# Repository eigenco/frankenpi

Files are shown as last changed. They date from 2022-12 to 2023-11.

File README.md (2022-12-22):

# frankenpi

This is an experimental project to connect Raspberry Pi with the help of cheap Cyclone IV FPGA board to 8-bit ISA bus to act as multiple different devices.

What is currently implemented (to some degree), i.e. PC can access through ISA
- Mass storage access from a file on the Raspberry Pi (written sectors are flushed every 2 seconds by default)
- Adlib output to optical SPDIF
- Sound Blaster 8-bit mono with DMA and IRQ (basic functions only), output to optical SPDIF
- Gravis Ultrasound (basic wavetable only), output to optical SPDIF
- Roland MT-32 (UART only), output to optical SPDIF
- USB mouse plugged into the Raspberry Pi will appear as a kind of serial mouse in DOS, custom ctmouse driver is provided (start with /v)
- Boot from custom TVGA9000i VGABIOS, i.e. no other devices are required to be present in the ISA bus besides FrakenPi and VGA-adapter

Youtube links:

https://www.youtube.com/watch?v=1ej76w8sHxY

https://www.youtube.com/watch?v=CkwgHHmKaSI

TESTED and working:
- Wolfenstein 3D (SB & Adlib)
- Second Reality (GUS)
- Scream Tracker 3.21 (SB1 and GUS)
- Skyroads (SB & Adlib)
- Keen 4 (Adlib)
- Monkey Island (Adlib/MT32/Mouse)
- Space Quest 3 (Adlib/Mouse)
- Space Quest 4 (Adlib/MT32/Mouse)
- Lotus 3 (Adlib)
- Lemmings (Adlib/Mouse)
- Eye of the Beholder I & II (Adlib/Mouse)
- Indiana Jones and the Fate of Atlantis (Adlib/MT32/Mouse)

Planned
- General MIDI
- MPU-401 support
- Sound Blaster AWE32 wavetable support
- Standard ATA at ports 1f0h-1f7h
- Compatibility improvements
- Boot ROM in the FPGA so hacked VGABIOS isn't required
- VGA output

Used resources
- Harddisk: ports 170h-171h
- SoundBlaster: ports 22ah-22eh corresponding ot base address of 220h, IRQ 7 and DMA 1
- MT32: 330h-331h
- Gravis Ultrasound: ports 341h-347h corresponding to base address of 240h
- Adlib: ports 388h-389h (standard)
- Mouse: port 3f8h and IRQ 4 (COM1)
- Bootcode for custom int 13h resides in hacked VGABIOS at the end of C0000-C7FFF memory region

Further explanation
- Outgoing port operations are transferred from the FPGA to the Raspberry Pi GPIO using dedicated unidirectional 8-bit data bus
- Incoming data from the Raspberry Pi GPIO (PCM, harddisk, mouse) is transferred using dedicated unidirectional 8-bit data bus
- Raspberry Pi: CPU0 handles hdd flushing and mouse, CPU1 handles GPIO transfers, CPU2 handles Adlib, Gravis Ultrasound and MT32 (software selected)
- Raspberry Pi operates with CPU1-CPU3 in isolated mode, all CPUs run at constant 1 GHz and sched_rt_runtime_us is -1
- Raspberry Pi generates sound data 64 samples at a time (16-bit stereo corresponds to 256 bytes it must transfer every 1.45ms or so)
- SPDIF is running in 24-bit 44100 Hz Stereo
- Hardcoded harddisk type is CHS 256/16/63, i.e. approx. 126MiB

Plan for the next PCB
- ICE40HX8K-CT256 (FPGA) seems to be available at Mouser
- IS61WV102416FBLL-10TLI (2 MByte SRAM) seem to be available at Mouser
- Created KiCAD project (PCB_v2)

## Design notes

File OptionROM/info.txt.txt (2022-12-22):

cf000h in binary is 1100 1111 0000 0000 0000

R0 1
R1 1
R2 1
R3 1
R4 0 (needs ground jumper)
R5 0 (needs ground jumpter)
R6 1
R7 1

[---]
[   ]
[---]
[   ]
[   ]
[   ]
[   ]
[   ]

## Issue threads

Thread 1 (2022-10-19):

FPGA Board

jshield, 2022-10-19:
Hello, I saw you mentioned using a cheap Altera Cyclone IV Board,

does it have a make/model, where did you source it from?

Cheers,

eigenco, 2022-10-19:
It was/is one of the brandless what used to be cheap Chinese Cyclone IV boards from ebay. Unfortunately getting FPGAs is next to impossible at the moment due to chip shortage. Someone might occasionally still sell them, but the prices are usually excessive. I paid for my board something like 10 eur before covid, but now I've seen sellers asking over 200 eur for similar very simple boards. When chips become available again, I might design my own PCB for whatever is properly available and makes sense then, perhaps even a complete self contained FPGA board so a separate module would not be needed, but for the moment it seems one has to wait.

AK6DN, 2022-11-13:
Are you running the Cyclone IV FPGA device out of spec? The Cyclone IV device has an absolute maximum limit of 4.2V on it's I/Os.
They are 3.3V I/O level compatible at most, they are NOT 5.0V I/O compatible.
The PC bus uses 5.0V I/O levels.
Normally one would use 5V/3.3V I/O translators on those signals (ie, like a TXB0104 device).

eigenco, 2022-11-14:
Yes, the input voltage is out of spec. Never the less, it doesn't seem to be problem so far. I've run the board for 100s of hours without an issue so I will probably only make changes if I design a new board for broad audience, but so far when FPGAs are not available I didn't bother with it as software development didn't suffer.

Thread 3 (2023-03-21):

Mass-stogate: Mounting of remote filesystems (instead of block images) on raspberry pi is possible.

peterzieba, 2023-03-21:
Hi,

I wanted to mention that for the mass-storage functionality, I think it should be possible to mount an entire filesystem on the raspberry pi without having to treat it as block device image and periodic sync/flush.

This can be achieved using Int 2Fh, which was originally intended to allow dos to mount network filesystems, but is also used by MSCDEX and such. This apparently works in any MS-DOS version since 3.3, and is used by projects like Netpi-IDE

https://web.archive.org/web/20221201103702/https://www.retrotronics.org/home-page/netpi-ide/

Essentially, a small TSR on the DOS side would use Int 2F to export a whole filesystem off of the Pi, at which point the possibilities on the Pi side are almost endless for different filesystem and network shares. Communication between the Pi and the host machine would simply be over an IO port, and a daemon on the Pi end listening to that address would receive requests from the TSR and serve files/directory information accordingly.

This eliminates sync problems, mounting, etc.

Anyway, I love seeing ISA bus projects!

Cheers

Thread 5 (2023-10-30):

Reverse FrankenPi (PiFranken?)

jamesfmackenzie, 2023-10-30:
The idea of connecting the Pi to an ISA backplane really appeals to me. So the Pi emulates an 8088 CPU, and can interface with peripherals like sound cards, network cards, video cards etc on an ISA bus.

Could the FrankenPi be used in "reverse" like this?

eigenco, 2023-11-06:
I did something like this corresponding to my RPiISA repository here now:

https://www.youtube.com/watch?v=V3mTAtPauRs

jamesfmackenzie, 2023-11-07:
This is fantastic! Would love to try this out too, but unfortunately I'm a software developer with no soldering skills :-)

Thanks for the KiCAD files! Can I get a company like JLCPCB to assemble, or is hand soldering still required for some components?

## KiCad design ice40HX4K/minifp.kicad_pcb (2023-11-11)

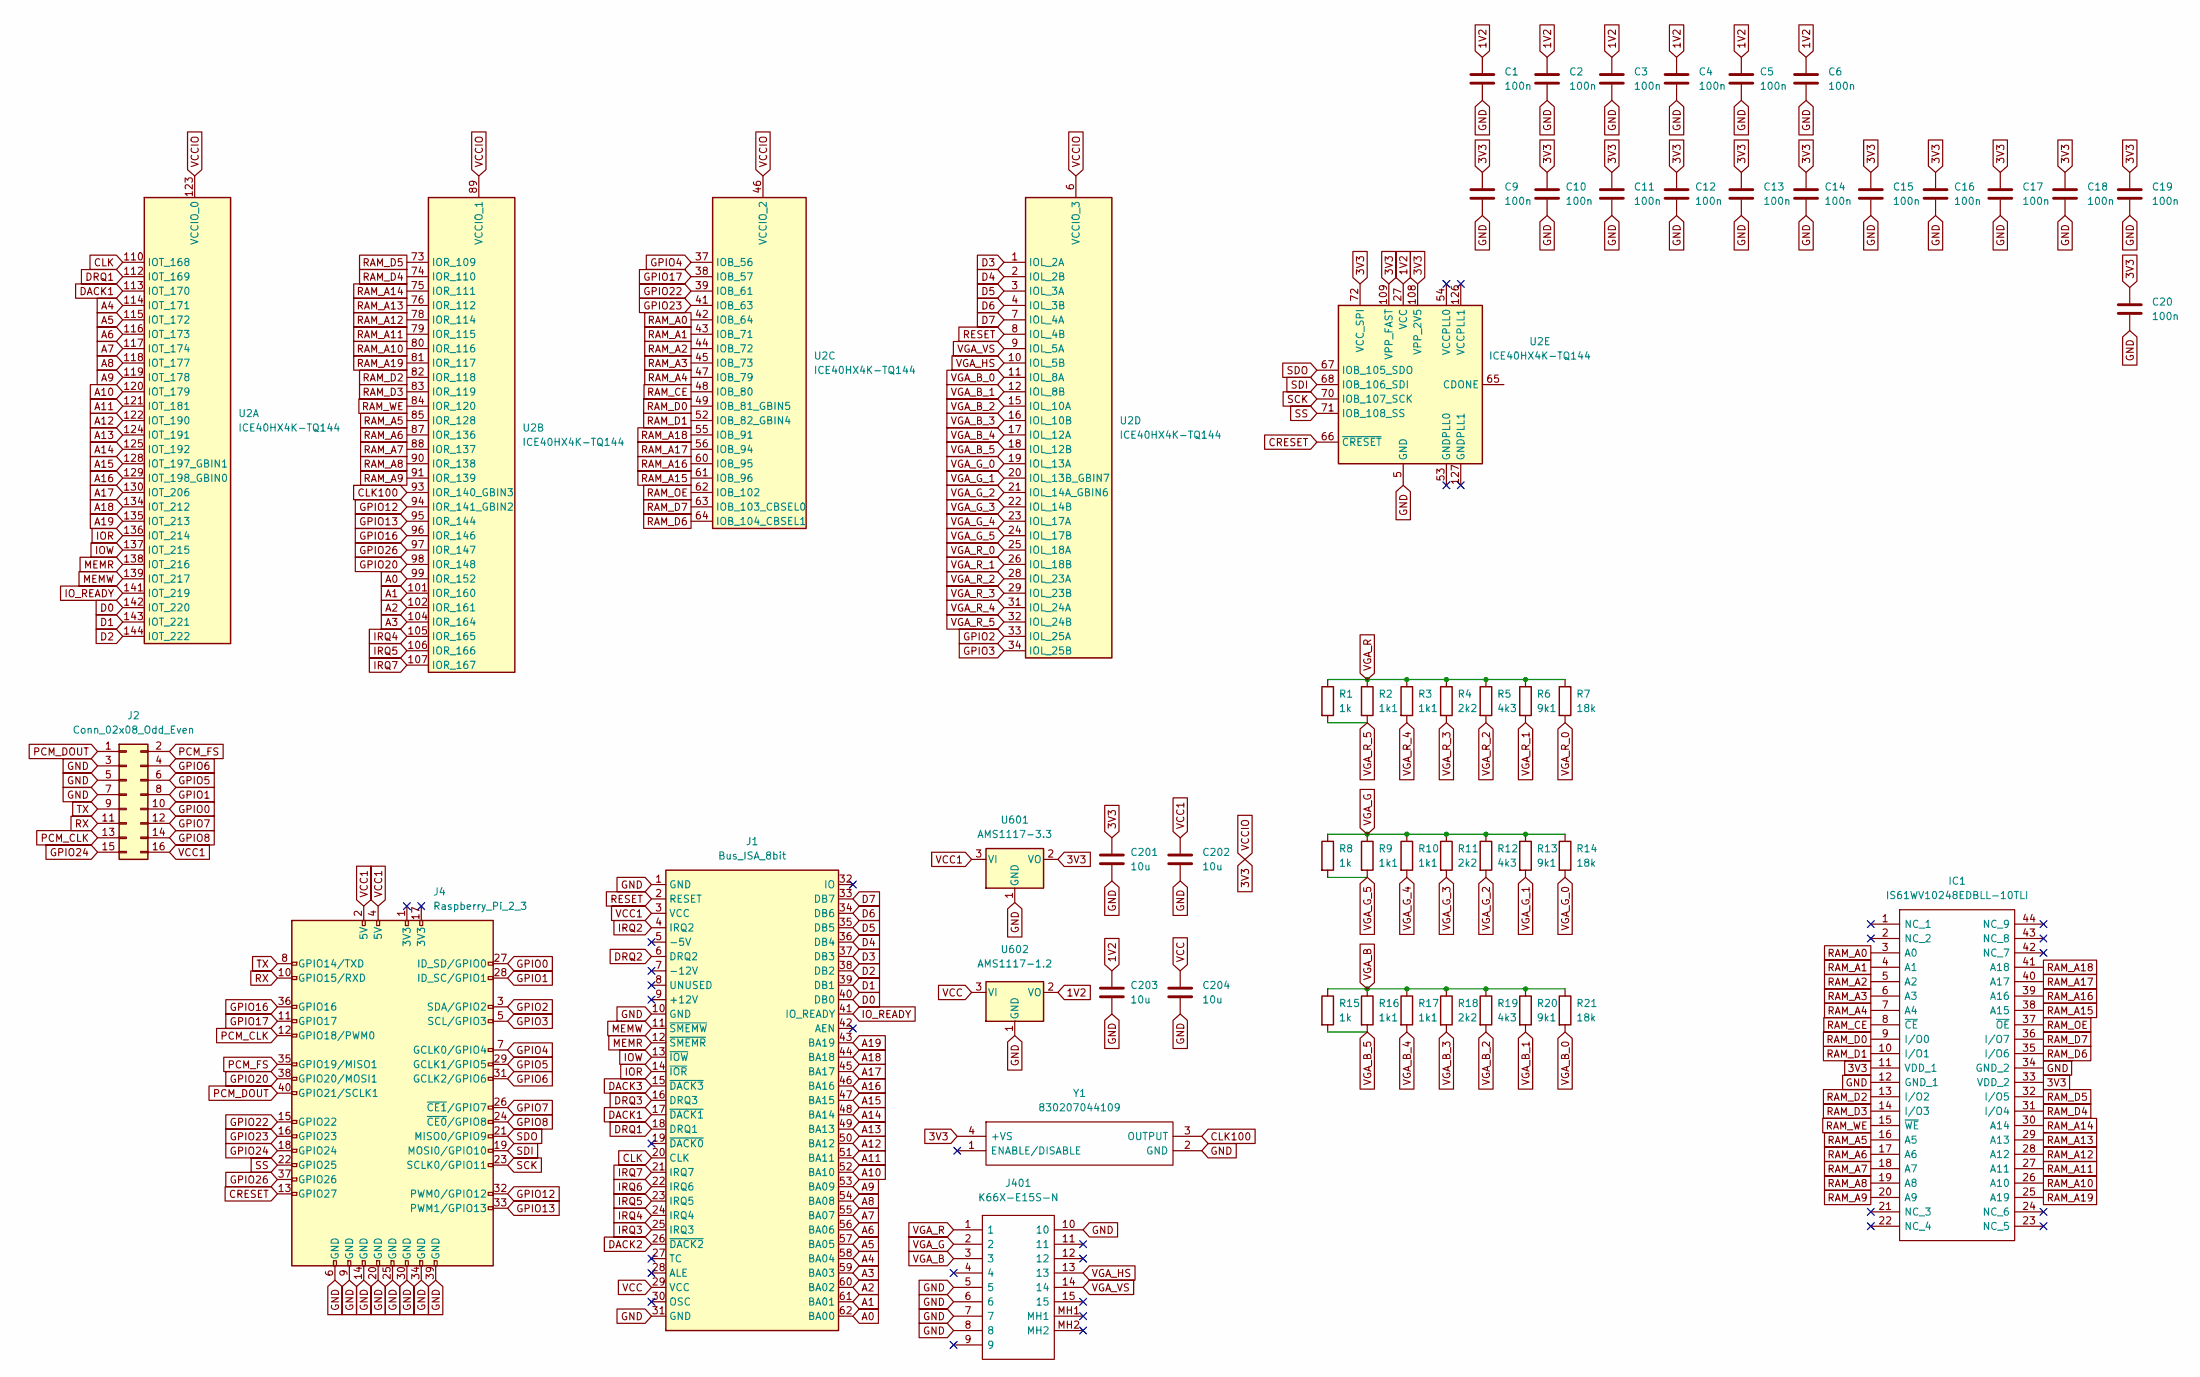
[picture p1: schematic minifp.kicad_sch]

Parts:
C1, C2, C3, C4, C5, C6, C9, C10, C11, C12, C13, C14, C15, C16, C17, C18, C19, C20: 100n; C_0603_1608Metric
C201, C202, C203, C204: 10u; C_0603_1608Metric
IC1: IS61WV10248EDBLL-10TLI; SOP80P1176X120-44N; Mouser Part Number 870-61WV10EDBLL10TLI
J1: Bus_ISA_8bit; Conn_Bus_ISA8
J2: Conn_02x08_Odd_Even; PinHeader_2x08_P1.27mm_Vertical
J4: Raspberry_Pi_2_3; PinHeader_2x20_P2.54mm_Vertical
J401: K66X-E15S-N; K66XE15SN; Mouser Part Number 806-K66X-E15S-N
R1, R8, R15: 1k; R_0603_1608Metric
R2, R3, R9, R10, R16, R17: 1k1; R_0603_1608Metric
R4, R11, R18: 2k2; R_0603_1608Metric
R5, R12, R19: 4k3; R_0603_1608Metric
R6, R13, R20: 9k1; R_0603_1608Metric
R7, R14, R21: 18k; R_0603_1608Metric
U2: ICE40HX4K-TQ144; TQFP-144_20x20mm_P0.5mm
U601: AMS1117-3.3; SOT-223-3_TabPin2
U602: AMS1117-1.2; SOT-223-3_TabPin2
Y1: 830207044109; Manufacturer_Part_Number 830207044109

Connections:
1V2: C1.1, C2.1, C3.1, C4.1, C5.1, C6.1, C203.1, U2.27 (VCC), U2.40 (VCC), U2.92 (VCC), U2.111 (VCC), U602.2 (VO)
3V3: C9.1, C10.1, C11.1, C12.1, C13.1, C14.1, C15.1, C16.1, C17.1, C18.1, C19.1, C20.1, C201.1, IC1.11 (VDD_1), IC1.33 (VDD_2), U2.6 (VCCIO_3), U2.30 (VCCIO_3), U2.46 (VCCIO_2), U2.57 (VCCIO_2), U2.72 (VCC_SPI), U2.89 (VCCIO_1), U2.100 (VCCIO_1), U2.108 (VPP_2V5), U2.109 (VPP_FAST), U2.123 (VCCIO_0), U2.131 (VCCIO_0), U601.2 (VO), Y1.4 (+VS)
A0: J1.62 (BA00), U2.99 (IOR_152)
A1: J1.61 (BA01), U2.101 (IOR_160)
A2: J1.60 (BA02), U2.102 (IOR_161)
A3: J1.59 (BA03), U2.104 (IOR_164)
A4: J1.58 (BA04), U2.114 (IOT_171)
A5: J1.57 (BA05), U2.115 (IOT_172)
A6: J1.56 (BA06), U2.116 (IOT_173)
A7: J1.55 (BA07), U2.117 (IOT_174)
A8: J1.54 (BA08), U2.118 (IOT_177)
A9: J1.53 (BA09), U2.119 (IOT_178)
A10: J1.52 (BA10), U2.120 (IOT_179)
A11: J1.51 (BA11), U2.121 (IOT_181)
A12: J1.50 (BA12), U2.122 (IOT_190)
A13: J1.49 (BA13), U2.124 (IOT_191)
A14: J1.48 (BA14), U2.125 (IOT_192)
A15: J1.47 (BA15), U2.128 (IOT_197_GBIN1)
A16: J1.46 (BA16), U2.129 (IOT_198_GBIN0)
A17: J1.45 (BA17), U2.130 (IOT_206)
A18: J1.44 (BA18), U2.134 (IOT_212)
A19: J1.43 (BA19), U2.135 (IOT_213)
CLK: J1.20 (CLK), U2.110 (IOT_168)
CLK100: U2.93 (IOR_140_GBIN3), Y1.3 (OUTPUT)
CRESET: J4.13 (GPIO27), U2.66 (~CRESET)
D0: J1.40 (DB0), U2.142 (IOT_220)
D1: J1.39 (DB1), U2.143 (IOT_221)
D2: J1.38 (DB2), U2.144 (IOT_222)
D3: J1.37 (DB3), U2.1 (IOL_2A)
D4: J1.36 (DB4), U2.2 (IOL_2B)
D5: J1.35 (DB5), U2.3 (IOL_3A)
D6: J1.34 (DB6), U2.4 (IOL_3B)
D7: J1.33 (DB7), U2.7 (IOL_4A)
DACK1: J1.17 (~DACK1), U2.113 (IOT_170)
DACK2: J1.26 (~DACK2)
DACK3: J1.15 (~DACK3)
DRQ1: J1.18 (DRQ1), U2.112 (IOT_169)
DRQ2: J1.6 (DRQ2)
DRQ3: J1.16 (DRQ3)
GND: C1.2, C2.2, C3.2, C4.2, C5.2, C6.2, C9.2, C10.2, C11.2, C12.2, C13.2, C14.2, C15.2, C16.2, C17.2, C18.2, C19.2, C20.2, C201.2, C202.2, C203.2, C204.2, IC1.12 (GND_1), IC1.34 (GND_2), J1.1 (GND), J1.10 (GND), J1.31 (GND), J2.3, J2.5, J2.7, J4.6 (GND), J4.9 (GND), J4.14 (GND), J4.20 (GND), J4.25 (GND), J4.30 (GND), J4.34 (GND), J4.39 (GND), J401.5, J401.6, J401.7, J401.8, J401.10, U2.5 (GND), U2.13 (GND), U2.14 (GND), U2.59 (GND), U2.69 (GND), U2.86 (GND), U2.103 (GND), U2.132 (GND), U2.140 (GND), U601.1 (GND), U602.1 (GND), Y1.2 (GND)
GPIO0: J2.10, J4.27 (ID_SD/GPIO0)
GPIO1: J2.8, J4.28 (ID_SC/GPIO1)
GPIO2: J4.3 (SDA/GPIO2), U2.33 (IOL_25A)
GPIO3: J4.5 (SCL/GPIO3), U2.34 (IOL_25B)
GPIO4: J4.7 (GCLK0/GPIO4), U2.37 (IOB_56)
GPIO5: J2.6, J4.29 (GCLK1/GPIO5)
GPIO6: J2.4, J4.31 (GCLK2/GPIO6)
GPIO7: J2.12, J4.26 (~CE1/GPIO7)
GPIO8: J2.14, J4.24 (~CE0/GPIO8)
GPIO12: J4.32 (PWM0/GPIO12), U2.94 (IOR_141_GBIN2)
GPIO13: J4.33 (PWM1/GPIO13), U2.95 (IOR_144)
GPIO16: J4.36 (GPIO16), U2.96 (IOR_146)
GPIO17: J4.11 (GPIO17), U2.38 (IOB_57)
GPIO20: J4.38 (GPIO20/MOSI1), U2.98 (IOR_148)
GPIO22: J4.15 (GPIO22), U2.39 (IOB_61)
GPIO23: J4.16 (GPIO23), U2.41 (IOB_63)
GPIO24: J2.15, J4.18 (GPIO24)
GPIO26: J4.37 (GPIO26), U2.97 (IOR_147)
IOR: J1.14 (~IOR), U2.136 (IOT_214)
IOW: J1.13 (~IOW), U2.137 (IOT_215)
IO_READY: J1.41 (IO_READY), U2.141 (IOT_219)
IRQ2: J1.4 (IRQ2)
IRQ3: J1.25 (IRQ3)
IRQ4: J1.24 (IRQ4), U2.105 (IOR_165)
IRQ5: J1.23 (IRQ5), U2.106 (IOR_166)
IRQ6: J1.22 (IRQ6)
IRQ7: J1.21 (IRQ7), U2.107 (IOR_167)
MEMR: J1.12 (~SMEMR), U2.138 (IOT_216)
MEMW: J1.11 (~SMEMW), U2.139 (IOT_217)
PCM_CLK: J2.13, J4.12 (GPIO18/PWM0)
PCM_DOUT: J2.1, J4.40 (GPIO21/SCLK1)
PCM_FS: J2.2, J4.35 (GPIO19/MISO1)
RAM_A0: IC1.3 (A0), U2.42 (IOB_64)
RAM_A1: IC1.4 (A1), U2.43 (IOB_71)
RAM_A2: IC1.5 (A2), U2.44 (IOB_72)
RAM_A3: IC1.6 (A3), U2.45 (IOB_73)
RAM_A4: IC1.7 (A4), U2.47 (IOB_79)
RAM_A5: IC1.16 (A5), U2.85 (IOR_128)
RAM_A6: IC1.17 (A6), U2.87 (IOR_136)
RAM_A7: IC1.18 (A7), U2.88 (IOR_137)
RAM_A8: IC1.19 (A8), U2.90 (IOR_138)
RAM_A9: IC1.20 (A9), U2.91 (IOR_139)
RAM_A10: IC1.26 (A10), U2.80 (IOR_116)
RAM_A11: IC1.27 (A11), U2.79 (IOR_115)
RAM_A12: IC1.28 (A12), U2.78 (IOR_114)
RAM_A13: IC1.29 (A13), U2.76 (IOR_112)
RAM_A14: IC1.30 (A14), U2.75 (IOR_111)
RAM_A15: IC1.38 (A15), U2.61 (IOB_96)
RAM_A16: IC1.39 (A16), U2.60 (IOB_95)
RAM_A17: IC1.40 (A17), U2.56 (IOB_94)
RAM_A18: IC1.41 (A18), U2.55 (IOB_91)
RAM_A19: IC1.25 (A19), U2.81 (IOR_117)
RAM_CE: IC1.8 (~CE), U2.48 (IOB_80)
RAM_D0: IC1.9 (I/O0), U2.49 (IOB_81_GBIN5)
RAM_D1: IC1.10 (I/O1), U2.52 (IOB_82_GBIN4)
RAM_D2: IC1.13 (I/O2), U2.82 (IOR_118)
RAM_D3: IC1.14 (I/O3), U2.83 (IOR_119)
RAM_D4: IC1.31 (I/O4), U2.74 (IOR_110)
RAM_D5: IC1.32 (I/O5), U2.73 (IOR_109)
RAM_D6: IC1.35 (I/O6), U2.64 (IOB_104_CBSEL1)
RAM_D7: IC1.36 (I/O7), U2.63 (IOB_103_CBSEL0)
RAM_OE: IC1.37 (~OE), U2.62 (IOB_102)
RAM_WE: IC1.15 (~WE), U2.84 (IOR_120)
RESET: J1.2 (RESET), U2.8 (IOL_4B)
RX: J2.11, J4.10 (GPIO15/RXD)
SCK: J4.23 (SCLK0/GPIO11), U2.70 (IOB_107_SCK)
SDI: J4.19 (MOSI0/GPIO10), U2.68 (IOB_106_SDI)
SDO: J4.21 (MISO0/GPIO9), U2.67 (IOB_105_SDO)
SS: J4.22 (GPIO25), U2.71 (IOB_108_SS)
TX: J2.9, J4.8 (GPIO14/TXD)
VCC: C204.1, J1.29 (VCC), U602.3 (VI)
VCC1: C202.1, J1.3 (VCC), J2.16, J4.2 (5V), J4.4 (5V), U601.3 (VI)
VGA_B: J401.3, R15.1, R16.1, R17.1, R18.1, R19.1, R20.1, R21.1
VGA_B_0: R21.2, U2.11 (IOL_8A)
VGA_B_1: R20.2, U2.12 (IOL_8B)
VGA_B_2: R19.2, U2.15 (IOL_10A)
VGA_B_3: R18.2, U2.16 (IOL_10B)
VGA_B_4: R17.2, U2.17 (IOL_12A)
VGA_B_5: R15.2, R16.2, U2.18 (IOL_12B)
VGA_G: J401.2, R8.1, R9.1, R10.1, R11.1, R12.1, R13.1, R14.1
VGA_G_0: R14.2, U2.19 (IOL_13A)
VGA_G_1: R13.2, U2.20 (IOL_13B_GBIN7)
VGA_G_2: R12.2, U2.21 (IOL_14A_GBIN6)
VGA_G_3: R11.2, U2.22 (IOL_14B)
VGA_G_4: R10.2, U2.23 (IOL_17A)
VGA_G_5: R8.2, R9.2, U2.24 (IOL_17B)
VGA_HS: J401.13, U2.10 (IOL_5B)
VGA_R: J401.1, R1.1, R2.1, R3.1, R4.1, R5.1, R6.1, R7.1
VGA_R_0: R7.2, U2.25 (IOL_18A)
VGA_R_1: R6.2, U2.26 (IOL_18B)
VGA_R_2: R5.2, U2.28 (IOL_23A)
VGA_R_3: R4.2, U2.29 (IOL_23B)
VGA_R_4: R3.2, U2.31 (IOL_24A)
VGA_R_5: R1.2, R2.2, U2.32 (IOL_24B)
VGA_VS: J401.14, U2.9 (IOL_5A)

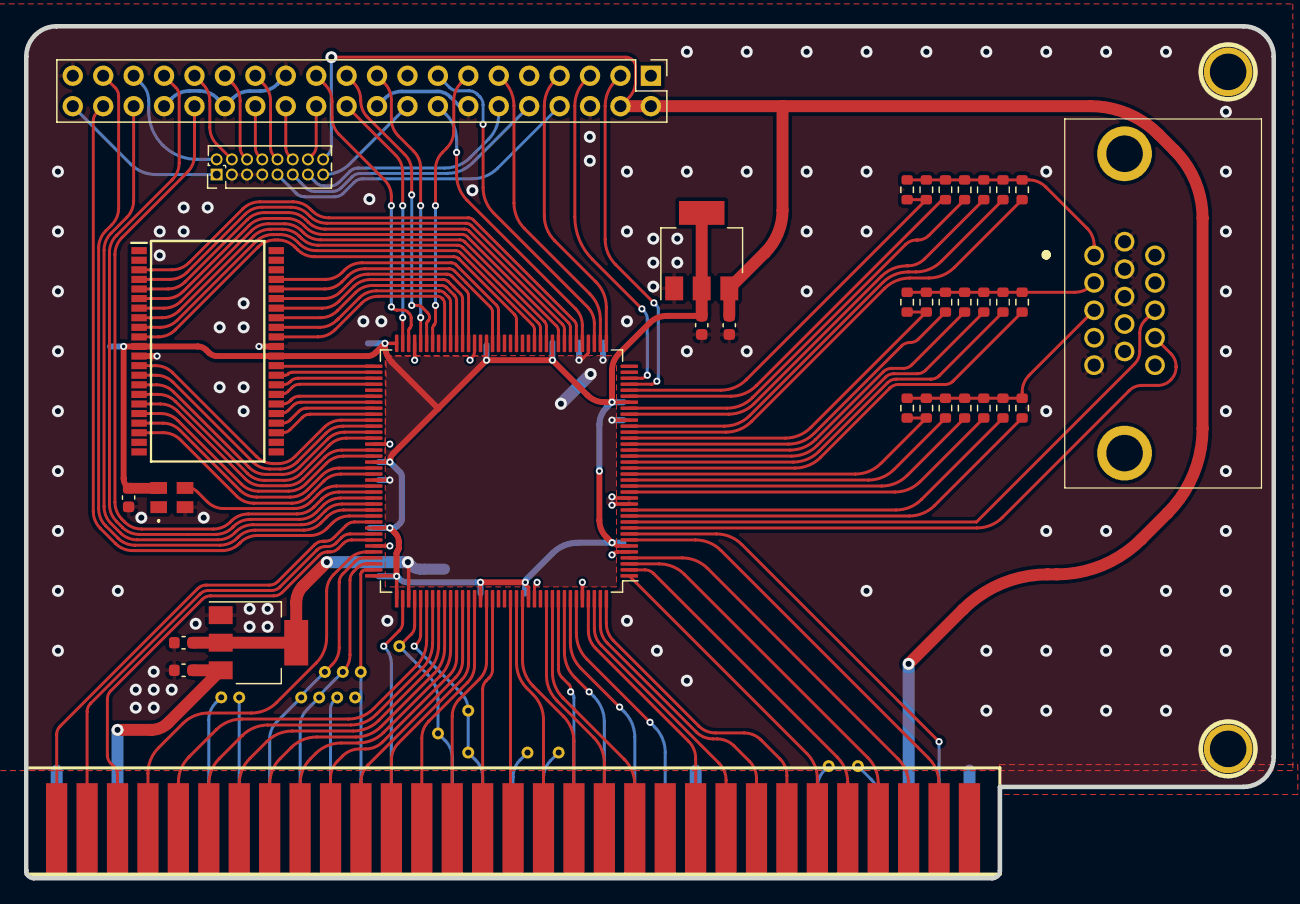
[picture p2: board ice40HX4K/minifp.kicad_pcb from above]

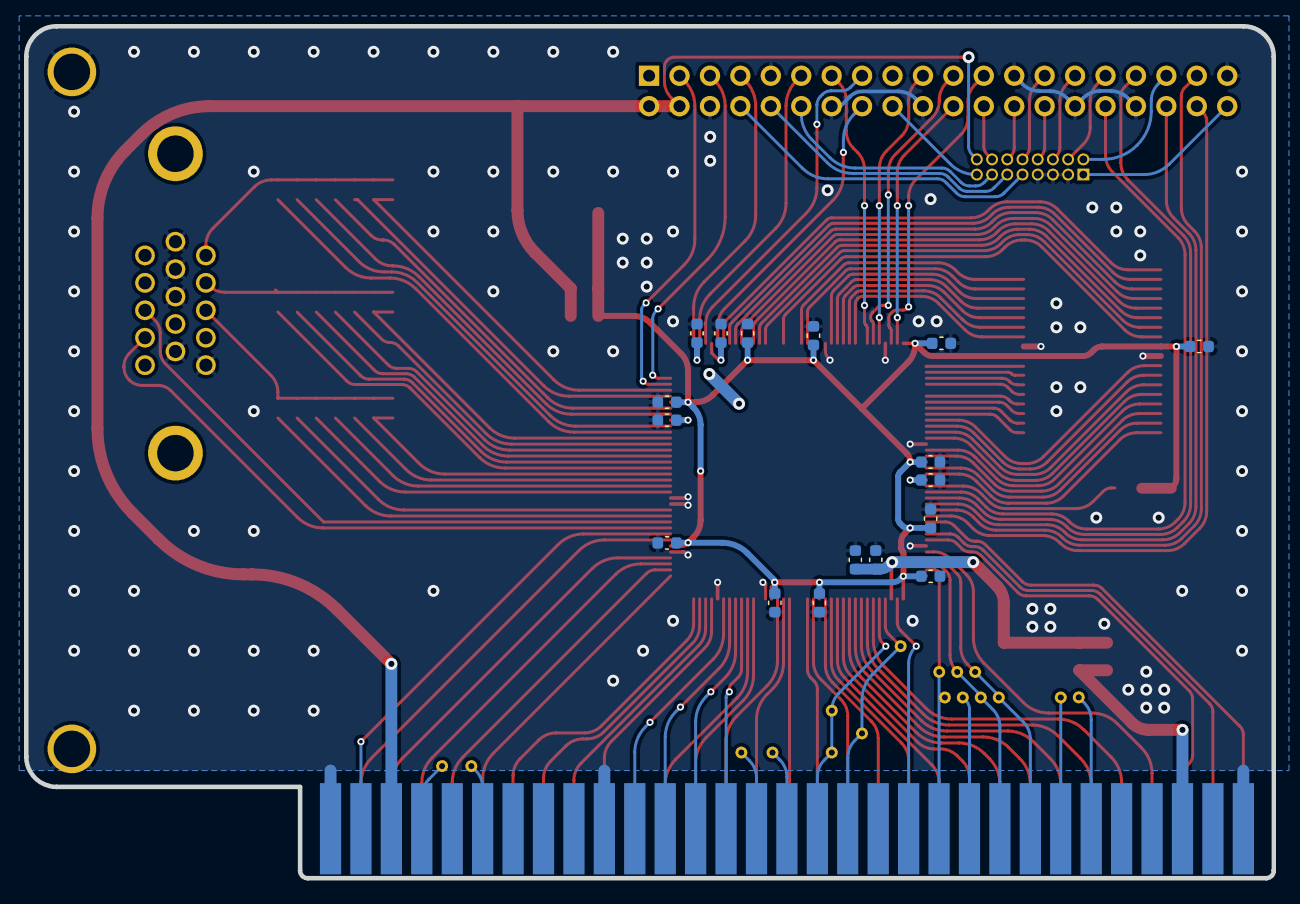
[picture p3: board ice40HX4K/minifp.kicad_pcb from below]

Board: 2 copper layers, 104.1 x 71.1 mm, 52 parts (17 on the bottom side), 128 nets.

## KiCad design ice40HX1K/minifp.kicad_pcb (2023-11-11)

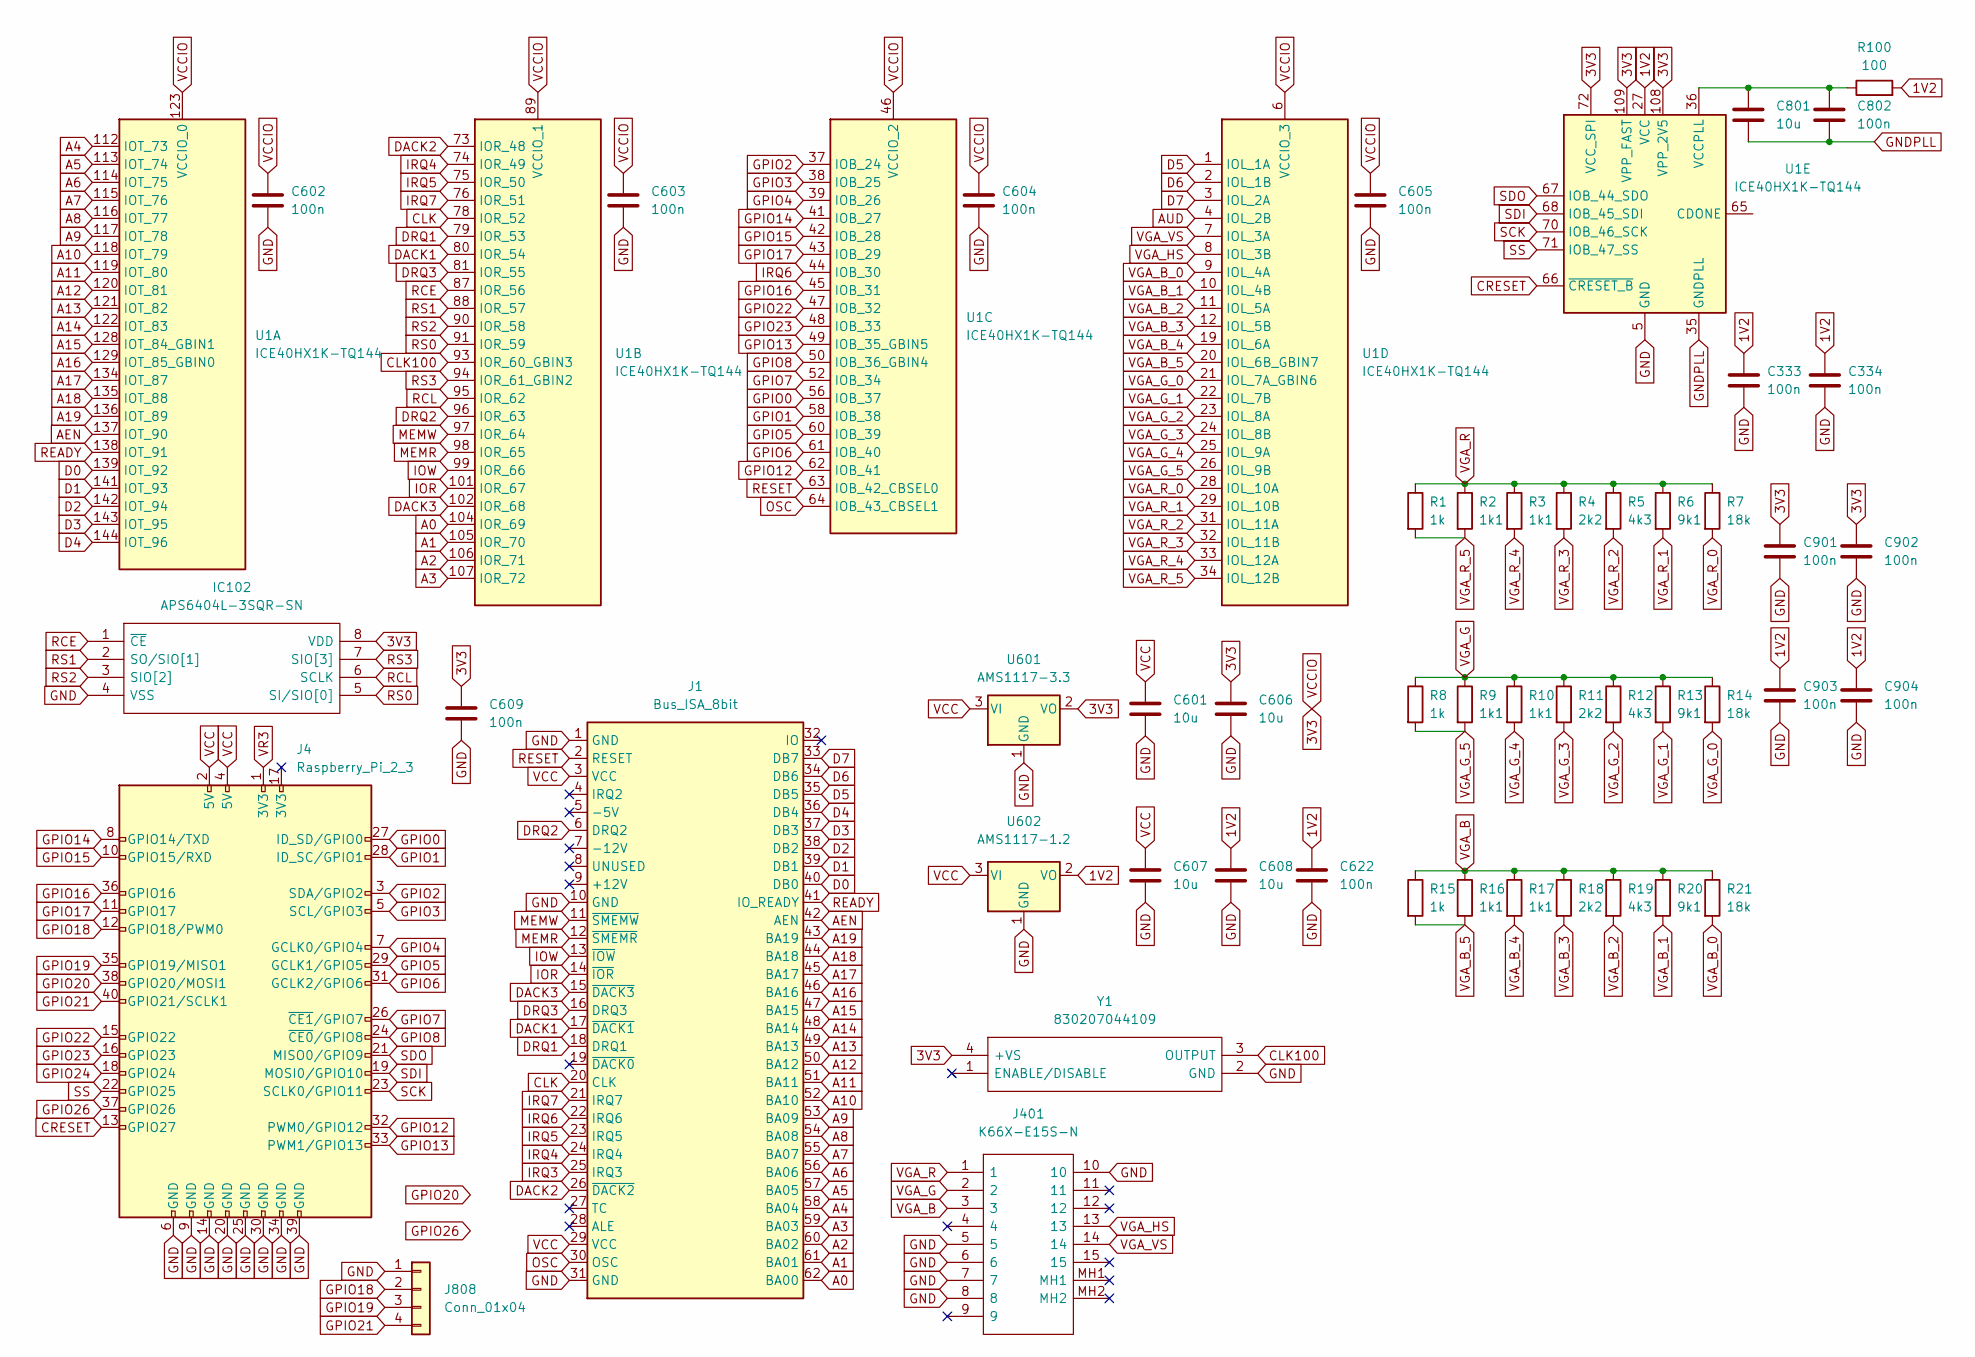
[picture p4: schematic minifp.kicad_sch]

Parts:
C333, C334, C602, C603, C604, C605, C609, C622, C802, C901, C902, C903, C904: 100n; C_0603_1608Metric
C601, C606, C607, C608, C801: 10u; C_0603_1608Metric
IC102: APS6404L-3SQR-SN; SOIC127P600X175-8N; Mouser Part Number 878-APS6404L-3SQR-SN
J1: Bus_ISA_8bit; Conn_Bus_ISA8
J4: Raspberry_Pi_2_3; PinHeader_2x20_P2.54mm_Vertical
J401: K66X-E15S-N; K66XE15SN; Mouser Part Number 806-K66X-E15S-N
J808: Conn_01x04; PinHeader_1x04_P2.54mm_Vertical
R1, R8, R15: 1k; R_0603_1608Metric
R2, R3, R9, R10, R16, R17: 1k1; R_0603_1608Metric
R4, R11, R18: 2k2; R_0603_1608Metric
R5, R12, R19: 4k3; R_0603_1608Metric
R6, R13, R20: 9k1; R_0603_1608Metric
R7, R14, R21: 18k; R_0603_1608Metric
R100: 100; R_0603_1608Metric
U1: ICE40HX1K-TQ144; TQFP-144_20x20mm_P0.5mm
U601: AMS1117-3.3; SOT-223-3_TabPin2
U602: AMS1117-1.2; SOT-223-3_TabPin2
Y1: 830207044109; Manufacturer_Part_Number 830207044109

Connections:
1V2: C333.1, C334.1, C608.1, C622.1, C903.1, C904.1, R100.2, U1.27 (VCC), U1.51 (VCC), U1.92 (VCC), U1.111 (VCC), U602.2 (VO)
3V3: C602.1, C603.1, C604.1, C605.1, C606.1, C609.1, C901.1, C902.1, IC102.8 (VDD), U1.6 (VCCIO_3), U1.30 (VCCIO_3), U1.46 (VCCIO_2), U1.57 (VCCIO_2), U1.72 (VCC_SPI), U1.89 (VCCIO_1), U1.100 (VCCIO_1), U1.108 (VPP_2V5), U1.109 (VPP_FAST), U1.123 (VCCIO_0), U1.133 (VCCIO_0), U601.2 (VO), Y1.4 (+VS)
A0: J1.62 (BA00), U1.104 (IOR_69)
A1: J1.61 (BA01), U1.105 (IOR_70)
A2: J1.60 (BA02), U1.106 (IOR_71)
A3: J1.59 (BA03), U1.107 (IOR_72)
A4: J1.58 (BA04), U1.112 (IOT_73)
A5: J1.57 (BA05), U1.113 (IOT_74)
A6: J1.56 (BA06), U1.114 (IOT_75)
A7: J1.55 (BA07), U1.115 (IOT_76)
A8: J1.54 (BA08), U1.116 (IOT_77)
A9: J1.53 (BA09), U1.117 (IOT_78)
A10: J1.52 (BA10), U1.118 (IOT_79)
A11: J1.51 (BA11), U1.119 (IOT_80)
A12: J1.50 (BA12), U1.120 (IOT_81)
A13: J1.49 (BA13), U1.121 (IOT_82)
A14: J1.48 (BA14), U1.122 (IOT_83)
A15: J1.47 (BA15), U1.128 (IOT_84_GBIN1)
A16: J1.46 (BA16), U1.129 (IOT_85_GBIN0)
A17: J1.45 (BA17), U1.134 (IOT_87)
A18: J1.44 (BA18), U1.135 (IOT_88)
A19: J1.43 (BA19), U1.136 (IOT_89)
AEN: J1.42 (AEN), U1.137 (IOT_90)
AUD: U1.4 (IOL_2B)
CLK: J1.20 (CLK), U1.78 (IOR_52)
CLK100: U1.93 (IOR_60_GBIN3), Y1.3 (OUTPUT)
CRESET: J4.13 (GPIO27), U1.66 (~CRESET_B)
D0: J1.40 (DB0), U1.139 (IOT_92)
D1: J1.39 (DB1), U1.141 (IOT_93)
D2: J1.38 (DB2), U1.142 (IOT_94)
D3: J1.37 (DB3), U1.143 (IOT_95)
D4: J1.36 (DB4), U1.144 (IOT_96)
D5: J1.35 (DB5), U1.1 (IOL_1A)
D6: J1.34 (DB6), U1.2 (IOL_1B)
D7: J1.33 (DB7), U1.3 (IOL_2A)
DACK1: J1.17 (~DACK1), U1.80 (IOR_54)
DACK2: J1.26 (~DACK2), U1.73 (IOR_48)
DACK3: J1.15 (~DACK3), U1.102 (IOR_68)
DRQ1: J1.18 (DRQ1), U1.79 (IOR_53)
DRQ2: J1.6 (DRQ2), U1.96 (IOR_63)
DRQ3: J1.16 (DRQ3), U1.81 (IOR_55)
GND: C333.2, C334.2, C601.2, C602.2, C603.2, C604.2, C605.2, C606.2, C607.2, C608.2, C609.2, C622.2, C901.2, C902.2, C903.2, C904.2, IC102.4 (VSS), J1.1 (GND), J1.10 (GND), J1.31 (GND), J4.6 (GND), J4.9 (GND), J4.14 (GND), J4.20 (GND), J4.25 (GND), J4.30 (GND), J4.34 (GND), J4.39 (GND), J401.5, J401.6, J401.7, J401.8, J401.10, J808.1, U1.5 (GND), U1.13 (GND), U1.14 (GND), U1.59 (GND), U1.69 (GND), U1.86 (GND), U1.103 (GND), U1.132 (GND), U1.140 (GND), U601.1 (GND), U602.1 (GND), Y1.2 (GND)
GNDPLL: C801.2, C802.2, U1.35 (GNDPLL)
GPIO0: J4.27 (ID_SD/GPIO0), U1.56 (IOB_37)
GPIO1: J4.28 (ID_SC/GPIO1), U1.58 (IOB_38)
GPIO2: J4.3 (SDA/GPIO2), U1.37 (IOB_24)
GPIO3: J4.5 (SCL/GPIO3), U1.38 (IOB_25)
GPIO4: J4.7 (GCLK0/GPIO4), U1.39 (IOB_26)
GPIO5: J4.29 (GCLK1/GPIO5), U1.60 (IOB_39)
GPIO6: J4.31 (GCLK2/GPIO6), U1.61 (IOB_40)
GPIO7: J4.26 (~CE1/GPIO7), U1.52 (IOB_34)
GPIO8: J4.24 (~CE0/GPIO8), U1.50 (IOB_36_GBIN4)
GPIO12: J4.32 (PWM0/GPIO12), U1.62 (IOB_41)
GPIO13: J4.33 (PWM1/GPIO13), U1.49 (IOB_35_GBIN5)
GPIO14: J4.8 (GPIO14/TXD), U1.41 (IOB_27)
GPIO15: J4.10 (GPIO15/RXD), U1.42 (IOB_28)
GPIO16: J4.36 (GPIO16), U1.45 (IOB_31)
GPIO17: J4.11 (GPIO17), U1.43 (IOB_29)
GPIO18: J4.12 (GPIO18/PWM0), J808.2
GPIO19: J4.35 (GPIO19/MISO1), J808.3
GPIO20: J4.38 (GPIO20/MOSI1)
GPIO21: J4.40 (GPIO21/SCLK1), J808.4
GPIO22: J4.15 (GPIO22), U1.47 (IOB_32)
GPIO23: J4.16 (GPIO23), U1.48 (IOB_33)
GPIO24: J4.18 (GPIO24)
GPIO26: J4.37 (GPIO26)
IOR: J1.14 (~IOR), U1.101 (IOR_67)
IOW: J1.13 (~IOW), U1.99 (IOR_66)
IRQ3: J1.25 (IRQ3)
IRQ4: J1.24 (IRQ4), U1.74 (IOR_49)
IRQ5: J1.23 (IRQ5), U1.75 (IOR_50)
IRQ6: J1.22 (IRQ6), U1.44 (IOB_30)
IRQ7: J1.21 (IRQ7), U1.76 (IOR_51)
MEMR: J1.12 (~SMEMR), U1.98 (IOR_65)
MEMW: J1.11 (~SMEMW), U1.97 (IOR_64)
unnamed: C801.1, C802.1, R100.1, U1.36 (VCCPLL)
OSC: J1.30 (OSC), U1.64 (IOB_43_CBSEL1)
RCE: IC102.1 (~CE), U1.87 (IOR_56)
RCL: IC102.6 (SCLK), U1.95 (IOR_62)
READY: J1.41 (IO_READY), U1.138 (IOT_91)
RESET: J1.2 (RESET), U1.63 (IOB_42_CBSEL0)
RS0: IC102.5 (SI/SIO[0]), U1.91 (IOR_59)
RS1: IC102.2 (SO/SIO[1]), U1.88 (IOR_57)
RS2: IC102.3 (SIO[2]), U1.90 (IOR_58)
RS3: IC102.7 (SIO[3]), U1.94 (IOR_61_GBIN2)
SCK: J4.23 (SCLK0/GPIO11), U1.70 (IOB_46_SCK)
SDI: J4.19 (MOSI0/GPIO10), U1.68 (IOB_45_SDI)
SDO: J4.21 (MISO0/GPIO9), U1.67 (IOB_44_SDO)
SS: J4.22 (GPIO25), U1.71 (IOB_47_SS)
VCC: C601.1, C607.1, J1.3 (VCC), J1.29 (VCC), J4.2 (5V), J4.4 (5V), U601.3 (VI), U602.3 (VI)
VGA_B: J401.3, R15.1, R16.1, R17.1, R18.1, R19.1, R20.1, R21.1
VGA_B_0: R21.2, U1.9 (IOL_4A)
VGA_B_1: R20.2, U1.10 (IOL_4B)
VGA_B_2: R19.2, U1.11 (IOL_5A)
VGA_B_3: R18.2, U1.12 (IOL_5B)
VGA_B_4: R17.2, U1.19 (IOL_6A)
VGA_B_5: R15.2, R16.2, U1.20 (IOL_6B_GBIN7)
VGA_G: J401.2, R8.1, R9.1, R10.1, R11.1, R12.1, R13.1, R14.1
VGA_G_0: R14.2, U1.21 (IOL_7A_GBIN6)
VGA_G_1: R13.2, U1.22 (IOL_7B)
VGA_G_2: R12.2, U1.23 (IOL_8A)
VGA_G_3: R11.2, U1.24 (IOL_8B)
VGA_G_4: R10.2, U1.25 (IOL_9A)
VGA_G_5: R8.2, R9.2, U1.26 (IOL_9B)
VGA_HS: J401.13, U1.8 (IOL_3B)
VGA_R: J401.1, R1.1, R2.1, R3.1, R4.1, R5.1, R6.1, R7.1
VGA_R_0: R7.2, U1.28 (IOL_10A)
VGA_R_1: R6.2, U1.29 (IOL_10B)
VGA_R_2: R5.2, U1.31 (IOL_11A)
VGA_R_3: R4.2, U1.32 (IOL_11B)
VGA_R_4: R3.2, U1.33 (IOL_12A)
VGA_R_5: R1.2, R2.2, U1.34 (IOL_12B)
VGA_VS: J401.14, U1.7 (IOL_3A)
VR3: J4.1 (3V3)

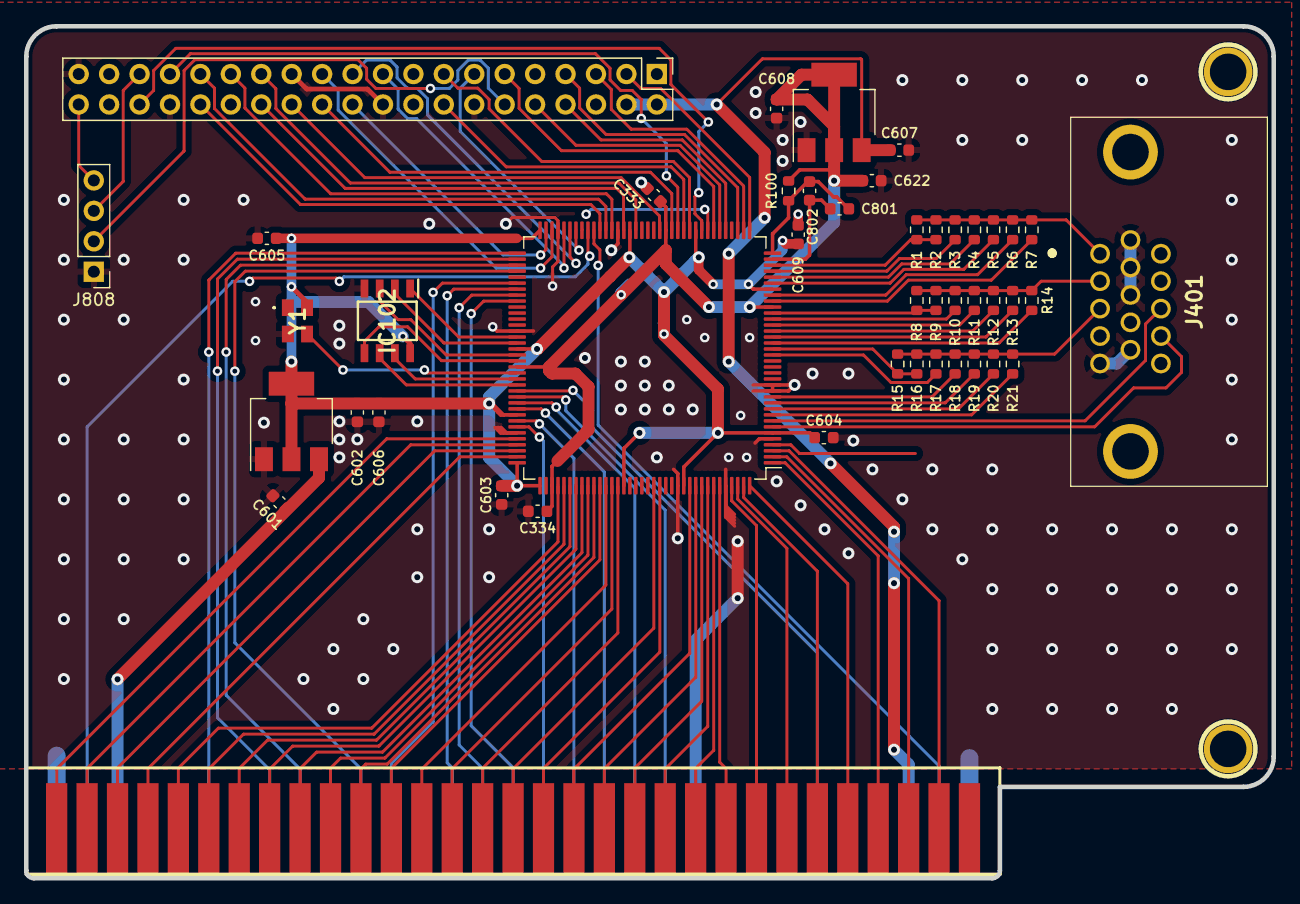
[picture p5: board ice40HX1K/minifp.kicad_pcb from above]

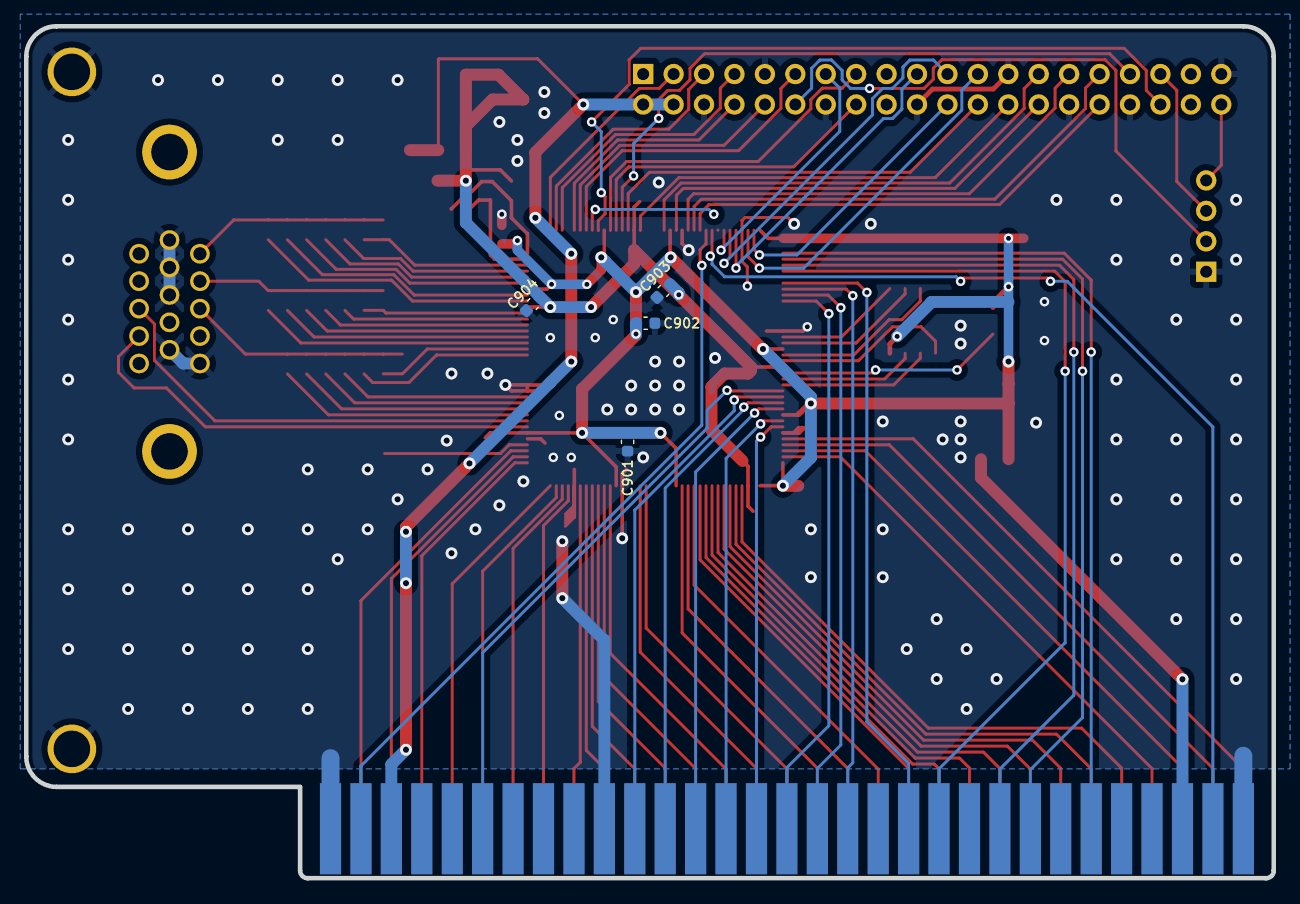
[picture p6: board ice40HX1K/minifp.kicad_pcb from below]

Board: 2 copper layers, 104.1 x 71.1 mm, 49 parts (4 on the bottom side), 108 nets.

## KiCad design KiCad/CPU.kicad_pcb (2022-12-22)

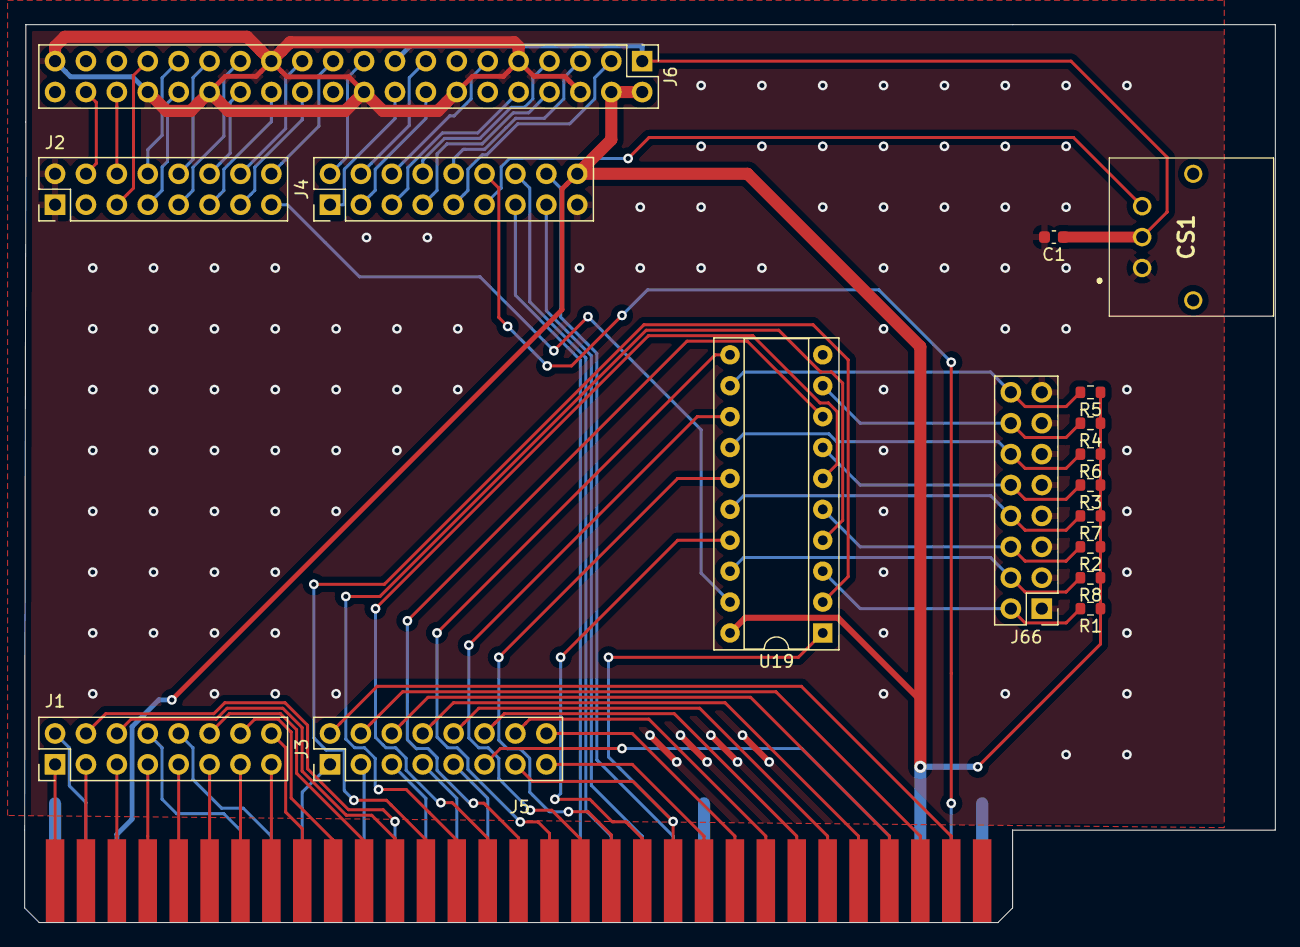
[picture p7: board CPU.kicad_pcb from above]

Board: 2 copper layers, 102.8 x 73.8 mm, 18 parts (0 on the bottom side), 80 nets.

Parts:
C1: 0.1u; C_0603_1608Metric
CS1: TOTX1350_F_; TOTX1350F
J1, J2, J3, J66: Conn_02x08_Odd_Even; PinHeader_2x08_P2.54mm_Vertical
J4: Conn_02x09_Odd_Even; PinHeader_2x09_P2.54mm_Vertical
J5: Bus_ISA_8bit; BUS_PC
J6: Raspberry_Pi_2_3; PinHeader_2x20_P2.54mm_Vertical
R1, R2, R3, R4, R5, R6, R7, R8: 10k; R_0603_1608Metric
U19: 74LS688; DIP-20_W7.62mm_Socket

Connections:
A0: J1.1, J5.62 (BA00)
A1: J1.3, J5.61 (BA01)
A2: J1.5, J5.60 (BA02)
A3: J1.7, J5.59 (BA03)
A4: J1.9, J5.58 (BA04)
A5: J1.11, J5.57 (BA05)
A6: J1.13, J5.56 (BA06)
A7: J1.15, J5.55 (BA07)
A8: J1.16, J5.54 (BA08)
A9: J1.14, J5.53 (BA09)
A10: J1.12, J5.52 (BA10)
A11: J1.6, J5.51 (BA11)
A12: J5.50 (BA12), U19.2 (P0)
A13: J5.49 (BA13), U19.4 (P1)
A14: J5.48 (BA14), U19.6 (P2)
A15: J5.47 (BA15), U19.8 (P3)
A16: J5.46 (BA16), U19.11 (P4)
A17: J5.45 (BA17), U19.13 (P5)
A18: J5.44 (BA18), U19.15 (P6)
A19: J5.43 (BA19), U19.17 (P7)
AEN: J3.13, J5.42 (AEN), U19.1 (G)
CLK: J1.4, J5.20 (CLK)
D0: J3.16, J5.40 (DB0)
D1: J3.14, J5.39 (DB1)
D2: J3.12, J5.38 (DB2)
D3: J3.10, J5.37 (DB3)
D4: J3.8, J5.36 (DB4)
D5: J3.6, J5.35 (DB5)
D6: J3.4, J5.34 (DB6)
D7: J3.2, J5.33 (DB7)
DRQ1: J3.7, J5.18 (DRQ1)
GND: C1.2, CS1.1 (NC_1), J2.1, J2.2, J4.17, J5.1 (GND), J5.10 (GND), J5.31 (GND), J6.6 (GND), J6.9 (GND), J6.14 (GND), J6.20 (GND), J6.25 (GND), J6.30 (GND), J6.34 (GND), J6.39 (GND), J66.1, J66.3, J66.5, J66.7, J66.9, J66.11, J66.13, J66.15, U19.10 (GND)
IO_READY: J3.15, J5.41 (IO_READY)
IRQ1: J3.5, J5.19 (~DACK0)
IRQ2: J3.11, J5.4 (IRQ2)
IRQ3: J1.8, J5.25 (IRQ3)
IRQ4: J1.10, J5.24 (IRQ4)
IRQ5: J3.1, J5.23 (IRQ5)
IRQ7: J3.3, J5.21 (IRQ7)
OSC: J1.2, J5.30 (OSC)
R0: J66.2, R1.2, U19.3 (R0)
R1: J66.6, R2.2, U19.5 (R1)
R2: J66.10, R3.2, U19.7 (R2)
R3: J66.14, R4.2, U19.9 (R3)
R4: J66.16, R5.2, U19.12 (R4)
R5: J66.12, R6.2, U19.14 (R5)
R6: J66.8, R7.2, U19.16 (R6)
R7: J66.4, R8.2, U19.18 (R7)
RESET: J4.12, J5.2 (RESET)
ROM: J2.15, U19.19 (P=R)
RP0: J2.9, J6.27 (ID_SD/GPIO0)
RP1: J2.12, J6.28 (ID_SC/GPIO1)
RP2: J4.9, J6.3 (SDA/GPIO2)
RP3: J4.10, J6.5 (SCL/GPIO3)
RP4: J4.8, J6.7 (GCLK0/GPIO4)
RP5: J2.10, J6.29 (GCLK1/GPIO5)
RP6: J2.8, J6.31 (GCLK2/GPIO6)
RP7: J2.11, J6.26 (~CE1/GPIO7)
RP8: J2.13, J6.24 (~CE0/GPIO8)
RP9: J2.16, J6.21 (MISO0/GPIO9)
RP10: J4.2, J6.19 (MOSI0/GPIO10)
RP11: J2.14, J6.23 (SCLK0/GPIO11)
RP12: J2.7, J6.32 (PWM0/GPIO12)
RP13: J2.5, J6.33 (PWM1/GPIO13)
RP14: J4.7, J6.8 (GPIO14/TXD)
RP15: J4.5, J6.10 (GPIO15/RXD)
RP16: J2.6, J6.36 (GPIO16)
RP17: J4.6, J6.11 (GPIO17)
RP18: J2.4, J6.38 (GPIO20/MOSI1)
RP19: J4.4, J6.15 (GPIO22)
RP20: J4.3, J6.16 (GPIO23)
RP21: J4.1, J6.18 (GPIO24)
SPDIF_OUT: CS1.3 (ANODE), J4.11
V3: C1.1, CS1.2 (CATHODE), J6.1 (3V3), J6.17 (3V3)
VCC: J4.18, J5.3 (VCC), J5.29 (VCC), J6.2 (5V), J6.4 (5V), R1.1, R2.1, R3.1, R4.1, R5.1, R6.1, R7.1, R8.1, U19.20 (VCC)
~DACK1: J3.9, J5.17 (~DACK1)
~IOR: J4.13, J5.14 (~IOR)
~IOW: J4.14, J5.13 (~IOW)
~MEMR: J4.15, J5.12 (~SMEMR)
~MEMW: J4.16, J5.11 (~SMEMW)

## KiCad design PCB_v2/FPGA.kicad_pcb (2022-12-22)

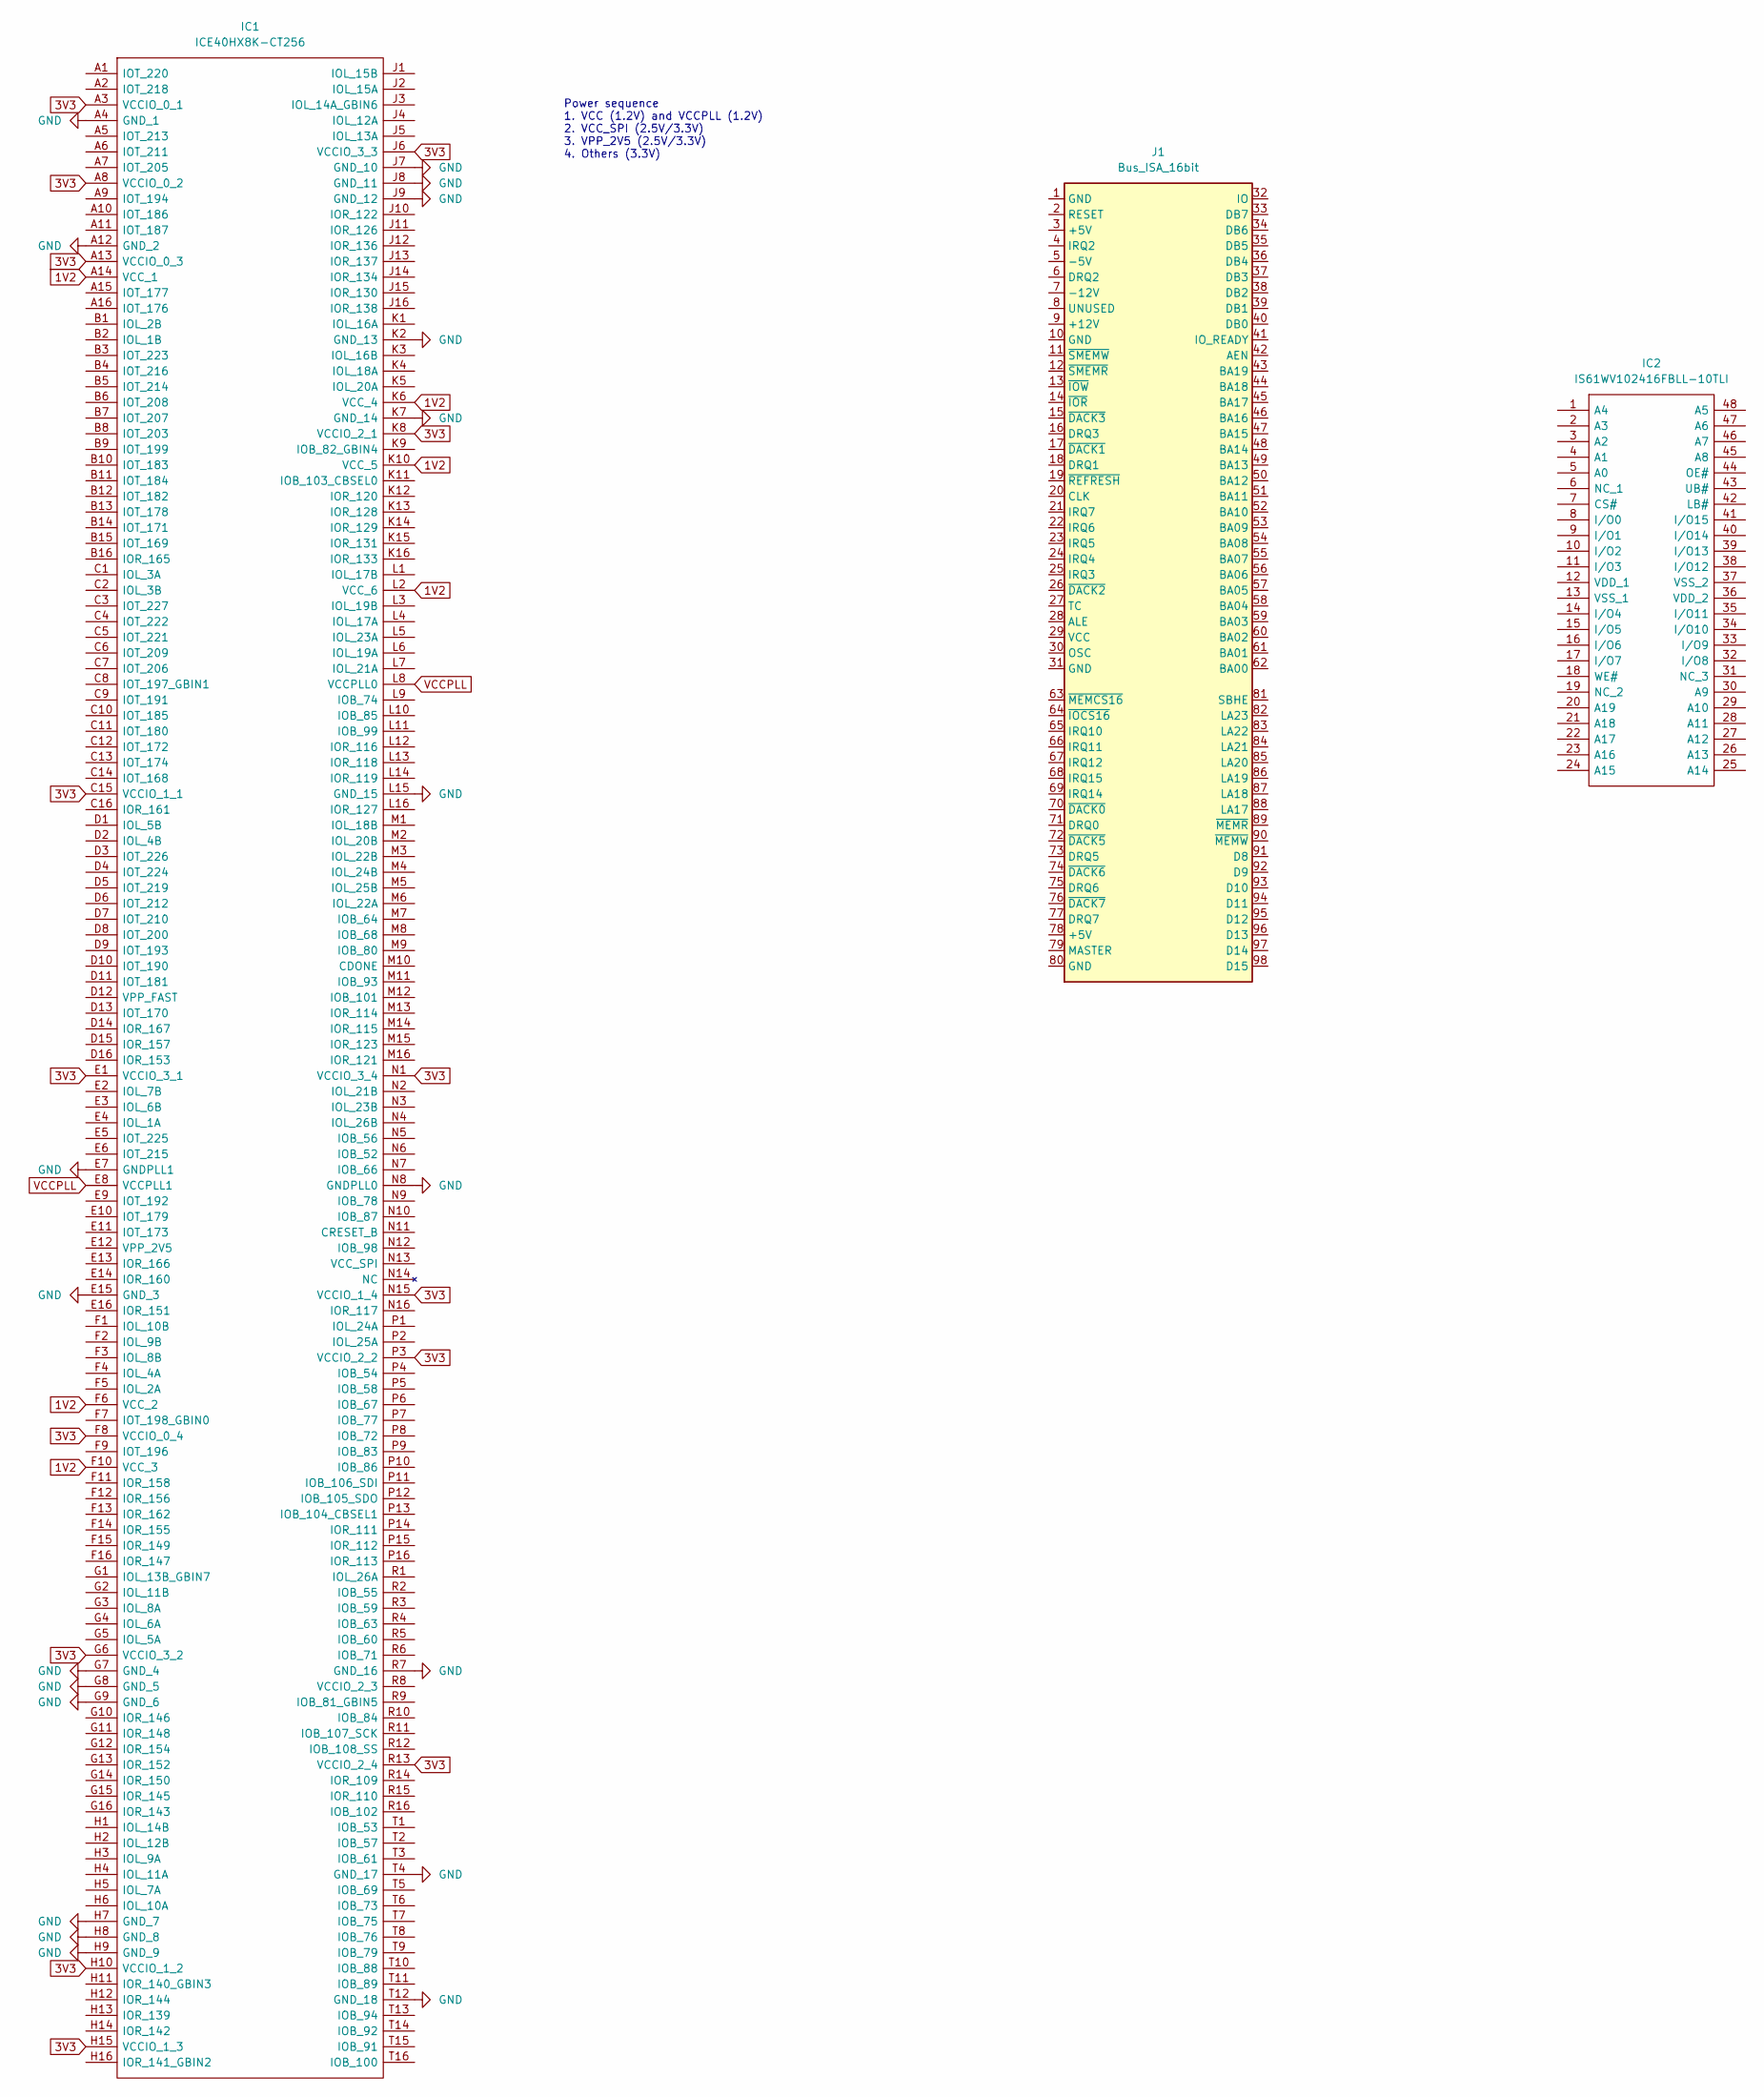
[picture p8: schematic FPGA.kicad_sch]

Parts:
IC1: ICE40HX8K-CT256; BGA256C80P16X16_1400X1400X170; Mouser Part Number 842-ICE40HX8K-CT256
IC2: IS61WV102416FBLL-10TLI; SOP50P2000X120-48N; Mouser Part Number 870-61WV12416FBL1TLI
J1: Bus_ISA_16bit; BUS_AT

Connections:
1V2: IC1.A14 (VCC_1), IC1.F6 (VCC_2), IC1.F10 (VCC_3), IC1.K6 (VCC_4), IC1.K10 (VCC_5), IC1.L2 (VCC_6)
3V3: IC1.A3 (VCCIO_0_1), IC1.A8 (VCCIO_0_2), IC1.A13 (VCCIO_0_3), IC1.C15 (VCCIO_1_1), IC1.E1 (VCCIO_3_1), IC1.F8 (VCCIO_0_4), IC1.G6 (VCCIO_3_2), IC1.H10 (VCCIO_1_2), IC1.H15 (VCCIO_1_3), IC1.J6 (VCCIO_3_3), IC1.K8 (VCCIO_2_1), IC1.N1 (VCCIO_3_4), IC1.N15 (VCCIO_1_4), IC1.P3 (VCCIO_2_2), IC1.R13 (VCCIO_2_4)
GND: IC1.A4 (GND_1), IC1.A12 (GND_2), IC1.E7 (GNDPLL1), IC1.E15 (GND_3), IC1.G7 (GND_4), IC1.G8 (GND_5), IC1.G9 (GND_6), IC1.H7 (GND_7), IC1.H8 (GND_8), IC1.H9 (GND_9), IC1.J7 (GND_10), IC1.J8 (GND_11), IC1.J9 (GND_12), IC1.K2 (GND_13), IC1.K7 (GND_14), IC1.L15 (GND_15), IC1.N8 (GNDPLL0), IC1.R7 (GND_16), IC1.T4 (GND_17), IC1.T12 (GND_18)
VCCPLL: IC1.E8 (VCCPLL1), IC1.L8 (VCCPLL0)

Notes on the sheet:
Power sequence 1. VCC (1.2V) and VCCPLL (1.2V) 2. VCC_SPI (2.5V/3.3V) 3. VPP_2V5 (2.5V/3.3V) 4. Others (3.3V)

Board: 2 copper layers, 3 parts (0 on the bottom side), 4 nets, no tracks yet.

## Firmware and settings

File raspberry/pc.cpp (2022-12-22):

/*
g++ -O2 -c opl.cpp;g++ -O2 -c gus.cpp
g++ -fsigned-char -O0 pc.cpp opl.o gus.o -lwiringPi -lm -lpthread -lmt32emu -o pc

run with run.sh and add to /boot/cmdline.txt isolcpus=1,2,3 before running
*/

#include <unistd.h>
#include <fcntl.h>
#include <sched.h>
#include <termios.h>
#include <stdio.h>
#include <stdlib.h>
#include <stdint.h>
#include <pthread.h>
#include <wiringPi.h>
#define MT32EMU_API_TYPE 3
#include <mt32emu/mt32emu.h>

void init_gus(void);
void write_gus(uint16_t addr, uint8_t data);
void GUS_CallBack(int16_t* buf, uint16_t len);
void adlib_init(uint32_t samplerate);
void adlib_write(uint16_t idx, uint8_t val);
void adlib_getsample(short* sndptr, short numsamples);

typedef uint8_t Bit8u;
typedef int16_t Bit16s;
typedef uint32_t Bit32u;

static uint8_t audio_busy = 0;
static uint8_t adlib_req = 0;
static uint8_t gus_req = 0;
//int16_t buf16[128];
static int16_t buf[128];
static int16_t buf2[128];
static uint8_t rx_buf[256];
static volatile uint8_t rx_read = 0;
static volatile uint8_t rx_write = 0;
uint8_t *hdd;
uint8_t dirty[256*16*63];
uint8_t dirt = 0;
FILE *hdd_file;
volatile int wr = 0;
static uint8_t mt32_buf[256];
static uint8_t mt32_rd = 0;
static uint8_t mt32_wr = 0;
static uint8_t adlib = 1;
static uint8_t mt32 = 0;
static uint8_t gus = 0;

#define DI0           0
#define DI1           1
#define DI2           2
#define DI3           3
#define DI4           4
#define DI5           5
#define DI6           6
#define DI7           7

#define DO0           8
#define DO1           9
#define DO2          10
#define DO3          11
#define DO4          12
#define DO5          13
#define DO6          14
#define DO7          15

#define CLOCK        16
#define FPGA_TX_REQ  17
#define FPGA_AU_REQ  20
#define STATE0       22
#define STATE1       23
#define STATE2       24

#define STATE_SY      0
#define STATE_TX      1
#define STATE_HD      2
#define STATE_AU      3
#define STATE_MOUSE   4

unsigned short ind() {
  unsigned short data;
  data  = digitalRead(DI7); data <<= 1;
  data |= digitalRead(DI6); data <<= 1;
  data |= digitalRead(DI5); data <<= 1;
  data |= digitalRead(DI4); data <<= 1;
  data |= digitalRead(DI3); data <<= 1;
  data |= digitalRead(DI2); data <<= 1;
  data |= digitalRead(DI1); data <<= 1;
  data |= digitalRead(DI0);
  return data;
}

void outd(unsigned char data) {
  digitalWrite(DO0, data & 1); data >>= 1;
  digitalWrite(DO1, data & 1); data >>= 1;
  digitalWrite(DO2, data & 1); data >>= 1;
  digitalWrite(DO3, data & 1); data >>= 1;
  digitalWrite(DO4, data & 1); data >>= 1;
  digitalWrite(DO5, data & 1); data >>= 1;
  digitalWrite(DO6, data & 1); data >>= 1;
  digitalWrite(DO7, data & 1);
}

void set_state(unsigned char state) {
  digitalWrite(STATE0, state & 1); state >>= 1;
  digitalWrite(STATE1, state & 1); state >>= 1;
  digitalWrite(STATE2, state & 1);
}

void CLK() {
  digitalWrite(CLOCK, 1);
  digitalWrite(CLOCK, 1);
  digitalWrite(CLOCK, 0);
  digitalWrite(CLOCK, 0);
}

void* adlib_worker(void*) {
  cpu_set_t cpuset;
  pthread_t thread;
  thread = pthread_self();
  CPU_ZERO(&cpuset);
  CPU_SET(2, &cpuset);
  pthread_setaffinity_np(thread, sizeof(cpuset), &cpuset);

  adlib_init(44100);
  while(adlib)
    if(adlib_req==1) {
      adlib_getsample(buf, 64);
      adlib_req = 2;
    }
  return NULL;
}

void* gus_worker(void*) {
  cpu_set_t cpuset;
  pthread_t thread;
  thread = pthread_self();
  CPU_ZERO(&cpuset);
  CPU_SET(2, &cpuset);
  pthread_setaffinity_np(thread, sizeof(cpuset), &cpuset);

  init_gus();
  while(gus)
    if(adlib_req==1) {
      GUS_CallBack(buf, 64);
      adlib_req = 2;
    }
  return NULL;
}

MT32Emu::Service *service;
void *mt32_worker(void*) {
  cpu_set_t cpuset;
  pthread_t thread;
  thread = pthread_self();
  CPU_ZERO(&cpuset);
  CPU_SET(2, &cpuset);
  pthread_setaffinity_np(thread, sizeof(cpuset), &cpuset);

  static mt32emu_report_handler_i mt32_rhi;
  service = new MT32Emu::Service();
  service->createContext(mt32_rhi, NULL);
  service->addROMFile("CM32L_CONTROL.ROM");
  service->addROMFile("CM32L_PCM.ROM");
  service->setStereoOutputSampleRate(44100);
  service->openSynth();

  while(mt32) {
    if(adlib_req==1) {
      for(int i=0; i<128; i++) buf[i] = buf2[i];
      adlib_req = 2;
      service->renderBit16s(buf2, 64);
    } /*else if(mt32_rd!=mt32_wr)
      service->parseStream((uint8_t*)&mt32_buf[mt32_rd++], 1);*/
  }
  return NULL;
}

void *mouse_worker(void *) {
  cpu_set_t cpuset;
  pthread_t thread;
  thread = pthread_self();
  CPU_ZERO(&cpuset);
  CPU_SET(0, &cpuset);
  pthread_setaffinity_np(thread, sizeof(cpuset), &cpuset);

  int mfile;
  char data[3];
  const char *mdev = "/dev/input/mouse0";
  mfile = open(mdev, O_RDONLY);
  for(;;) {
    if(!audio_busy)
      if(read(mfile, data, 3)==3) {
	data[1] = data[1]*0.5;
	data[2] = -data[2]*0.5;
        rx_buf[rx_write++] = 0x40|((data[0]&1)<<5)|((data[0]&2)<<3)|((data[2]&0xC0)>>4)|((data[1]&0xC0)>>6);
        rx_buf[rx_write++] = data[1]&63;
        rx_buf[rx_write++] = data[2]&63;
      } else usleep(10);
  }

  return NULL;
}

void *hdflush_worker(void *) {
  cpu_set_t cpuset;
  pthread_t thread;
  thread = pthread_self();
  CPU_ZERO(&cpuset);
  CPU_SET(0, &cpuset);
  pthread_setaffinity_np(thread, sizeof(cpuset), &cpuset);
  uint32_t i, j, k;

  hdd_file = fopen("compact.img", "rb+");
  for(;;) {
    usleep(2000000);
    if(dirt && !wr) {
      printf("<");
      fflush(stdout);
      for(i=0; i<256*16*63; i++)
        if(dirty[i]) {
          fseek(hdd_file, 512*i, SEEK_SET);
          fwrite(hdd+512*i, 512, 1, hdd_file);
          dirty[i] = 0;
          printf(".");
        }
      dirt = 0;
      fflush(hdd_file);
      printf(">\n");
      fflush(stdout);
    }
  }
  fclose(hdd_file);

  return NULL;
}

int main(void) {
  volatile int rd = 0, lba = 0, chs = 0, c = 0, h = 0, s = 0, i = 0, j;
  volatile unsigned char addr, data, areg, ad = 0;
  pthread_t thread_adlib, thread_gus, thread_mouse, thread_hdd, thread_mt32;

  s = 512*256*16*63;
  hdd = (uint8_t*)malloc(s);
  printf("Reading...\n");
  hdd_file = fopen("compact.img", "rb");
  c = fread(hdd, 1, s, hdd_file);
  printf("...got %d bytes\n", c);
  fclose(hdd_file);

  wiringPiSetupGpio();

  pinMode(DI0, INPUT);
  pinMode(DI1, INPUT);
  pinMode(DI2, INPUT);
  pinMode(DI3, INPUT);
  pinMode(DI4, INPUT);
  pinMode(DI5, INPUT);
  pinMode(DI6, INPUT);
  pinMode(DI7, INPUT);

  pinMode(DO0, OUTPUT);
  pinMode(DO1, OUTPUT);
  pinMode(DO2, OUTPUT);
  pinMode(DO3, OUTPUT);
  pinMode(DO4, OUTPUT);
  pinMode(DO5, OUTPUT);
  pinMode(DO6, OUTPUT);
  pinMode(DO7, OUTPUT);

  pinMode(CLOCK, OUTPUT);
  pinMode(FPGA_TX_REQ, INPUT);
  pinMode(FPGA_AU_REQ, INPUT);
  pinMode(STATE0, OUTPUT);
  pinMode(STATE1, OUTPUT);
  pinMode(STATE2, OUTPUT);

  // audio generating thread runs on isolated core 2
  pthread_create(&thread_adlib, NULL, adlib_worker, NULL);

  // gpio controlling thread runs on isolated core 1
  cpu_set_t cpuset;
  pthread_t thread;
  thread = pthread_self();
  CPU_ZERO(&cpuset);
  CPU_SET(1, &cpuset);
  pthread_setaffinity_np(thread, sizeof(cpuset), &cpuset);

  // miscellaneous threads run on core 0
  pthread_create(&thread_mouse, NULL, mouse_worker, NULL);
  pthread_create(&thread_hdd, NULL, hdflush_worker, NULL);

  for(;;) {
    set_state(STATE_SY);
    CLK();

    if(digitalRead(FPGA_TX_REQ)) {
      set_state(STATE_TX);
      CLK();
      CLK();
      CLK();
      data = ind();
      ad = ~ad;
      if(ad) addr = data;
      else {
        if(addr==0x32) {
          if(data==0) { adlib = 0; mt32 = 0; gus = 0; }
          if(data==1) { adlib = 1; mt32 = 0; gus = 0; pthread_create(&thread_adlib, NULL, adlib_worker, NULL); }
          if(data==2) { adlib = 0; mt32 = 1; gus = 0; pthread_create(&thread_mt32, NULL, mt32_worker, NULL); }
          if(data==3) { adlib = 0; mt32 = 0; gus = 1; pthread_create(&thread_gus, NULL, gus_worker, NULL); }
        }
        if(addr==0x30) service->parseStream((uint8_t*)&data, 1);
        //if(addr==0x30) mt32_buf[mt32_wr++] = data;
	if(addr>0x40 && addr<0x49) write_gus(0x300|addr, data);
        if(addr==0x70) {
          if(data==0) { rd = 0; wr = 512; chs=0; }
          if(data==1) { rd = 512; wr = 0; }
        }
        if(addr==0x71) {
          if(chs==0) { c = data; chs++; }
          else if(chs==1) { h = data; chs++; }
          else if(chs==2) { s = data; chs++; lba = 512*(63*(16*c+h)+s-1); }
          else if(wr) { if(lba&511==511) dirty[lba>>9] = 1; hdd[lba++] = data; dirt = 1; }
        }
        if(addr==0x88) areg = data;
        if(addr==0x89) adlib_write(areg, data);
      }
    }

    if(audio_busy) {
      set_state(STATE_AU);
      outd((buf[(64-audio_busy)<<1]>>8));
      CLK();
      outd((buf[(64-audio_busy)<<1]&255));
      CLK();
      outd((buf[((64-audio_busy)<<1)+1]>>8));
      CLK();
      outd((buf[((64-audio_busy)<<1)+1]&255));
      CLK();
      CLK();
      CLK();
      audio_busy--;
    } else {
      if(digitalRead(FPGA_AU_REQ) && adlib_req==0)
        adlib_req = 1;
      if(rd) {
        set_state(STATE_HD);
        outd(hdd[lba++]);
        CLK();
        rd--;
      }
      if(rx_read!=rx_write) {
        set_state(STATE_MOUSE);
        outd(rx_buf[rx_read++]);
        CLK();
      }
    }
    if(adlib_req == 2) {
      audio_busy = 64;
      adlib_req = 0;
    }
  }
  return 0;
}

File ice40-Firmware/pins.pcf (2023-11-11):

set_io ISA_D[0] 139
set_io ISA_D[1] 141
set_io ISA_D[2] 142
set_io ISA_D[3] 143
set_io ISA_D[4] 144
set_io ISA_D[5] 1
set_io ISA_D[6] 2
set_io ISA_D[7] 3

set_io ISA_A[0] 104
set_io ISA_A[1] 105
set_io ISA_A[2] 106
set_io ISA_A[3] 107
set_io ISA_A[4] 112
set_io ISA_A[5] 113
set_io ISA_A[6] 114
set_io ISA_A[7] 115
set_io ISA_A[8] 116
set_io ISA_A[9] 117
set_io ISA_A[10] 118
set_io ISA_A[11] 119
set_io ISA_A[12] 120
set_io ISA_A[13] 121
set_io ISA_A[14] 122
set_io ISA_A[15] 128
set_io ISA_A[16] 129
set_io ISA_A[17] 134
set_io ISA_A[18] 135
set_io ISA_A[19] 136

set_io ISA_MEMW 97
set_io ISA_MEMR 98
set_io ISA_IOW 99
set_io ISA_IOR 101

set_io VGA_VS 7
set_io VGA_HS 8

set_io VGA_B[0] 9
set_io VGA_B[1] 10
set_io VGA_B[2] 11
set_io VGA_B[3] 12
set_io VGA_B[4] 19
set_io VGA_B[5] 20

set_io VGA_G[0] 21
set_io VGA_G[1] 22
set_io VGA_G[2] 23
set_io VGA_G[3] 24
set_io VGA_G[4] 25
set_io VGA_G[5] 26

set_io VGA_R[0] 28
set_io VGA_R[1] 29
set_io VGA_R[2] 31
set_io VGA_R[3] 32
set_io VGA_R[4] 33
set_io VGA_R[5] 34

set_io RPI_GPIO[0] 56
set_io RPI_GPIO[1] 58
set_io RPI_GPIO[2] 37
set_io RPI_GPIO[3] 38
set_io RPI_GPIO[4] 39
set_io RPI_GPIO[5] 60
set_io RPI_GPIO[6] 61
set_io RPI_GPIO[7] 52
set_io RPI_GPIO[8] 50
set_io RPI_GPIO[9] 67
set_io RPI_GPIO[10] 68
set_io RPI_GPIO[11] 70
set_io RPI_GPIO[12] 62
set_io RPI_GPIO[13] 49
set_io RPI_GPIO[14] 41
set_io RPI_GPIO[15] 42
set_io RPI_GPIO[16] 45
set_io RPI_GPIO[17] 43
set_io RPI_GPIO[18] 44
set_io RPI_GPIO[22] 47
set_io RPI_GPIO[23] 48
set_io RPI_GPIO[25] 71
set_io RPI_GPIO[27] 66

set_io ISA_RESET 63
set_io ISA_OSC 64
set_io ISA_IRQ4 74
set_io ISA_IRQ5 75
set_io ISA_IRQ7 76
set_io ISA_CLK 78
set_io ISA_DRQ1 79
set_io ISA_DACK1 80
set_io ISA_DRQ2 96
set_io ISA_DACK2 73
set_io ISA_DRQ3 81
set_io ISA_DACK3 102
set_io ISA_AEN 137
set_io ISA_READY 138

set_io CLK 93

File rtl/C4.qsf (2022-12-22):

# -------------------------------------------------------------------------- #
#
# Copyright (C) 1991-2013 Altera Corporation
# Your use of Altera Corporation's design tools, logic functions 
# and other software and tools, and its AMPP partner logic 
# functions, and any output files from any of the foregoing 
# (including device programming or simulation files), and any 
# associated documentation or information are expressly subject 
# to the terms and conditions of the Altera Program License 
# Subscription Agreement, Altera MegaCore Function License 
# Agreement, or other applicable license agreement, including, 
# without limitation, that your use is for the sole purpose of 
# programming logic devices manufactured by Altera and sold by 
# Altera or its authorized distributors.  Please refer to the 
# applicable agreement for further details.
#
# -------------------------------------------------------------------------- #
#
# Quartus II 64-Bit
# Version 13.0.1 Build 232 06/12/2013 Service Pack 1 SJ Web Edition
# Date created = 14:09:58  December 04, 2021
#
# -------------------------------------------------------------------------- #
#
# Notes:
#
# 1) The default values for assignments are stored in the file:
#		C4_assignment_defaults.qdf
#    If this file doesn't exist, see file:
#		assignment_defaults.qdf
#
# 2) Altera recommends that you do not modify this file. This
#    file is updated automatically by the Quartus II software
#    and any changes you make may be lost or overwritten.
#
# -------------------------------------------------------------------------- #


set_global_assignment -name FAMILY "Cyclone IV E"
set_global_assignment -name DEVICE EP4CE6E22C8
set_global_assignment -name TOP_LEVEL_ENTITY C4
set_global_assignment -name ORIGINAL_QUARTUS_VERSION "13.0 SP1"
set_global_assignment -name PROJECT_CREATION_TIME_DATE "14:09:58  DECEMBER 04, 2021"
set_global_assignment -name LAST_QUARTUS_VERSION "13.0 SP1"
set_global_assignment -name PROJECT_OUTPUT_DIRECTORY output_files
set_global_assignment -name MIN_CORE_JUNCTION_TEMP 0
set_global_assignment -name MAX_CORE_JUNCTION_TEMP 85
set_global_assignment -name ERROR_CHECK_FREQUENCY_DIVISOR 1
set_global_assignment -name NOMINAL_CORE_SUPPLY_VOLTAGE 1.2V

set_location_assignment PIN_25 -to clk
set_location_assignment PIN_138 -to leds[0]
set_location_assignment PIN_141 -to leds[1]
set_location_assignment PIN_142 -to leds[2]
set_location_assignment PIN_143 -to leds[3]
set_location_assignment PIN_144 -to leds[4]
set_location_assignment PIN_1 -to leds[5]
set_location_assignment PIN_2 -to leds[6]
set_location_assignment PIN_3 -to leds[7]

set_global_assignment -name PARTITION_NETLIST_TYPE SOURCE -section_id Top
set_global_assignment -name PARTITION_FITTER_PRESERVATION_LEVEL PLACEMENT_AND_ROUTING -section_id Top
set_global_assignment -name PARTITION_COLOR 16764057 -section_id Top
set_global_assignment -name STRATIX_DEVICE_IO_STANDARD "2.5 V"
set_location_assignment PIN_49 -to A[9]
set_location_assignment PIN_51 -to A[8]
set_location_assignment PIN_50 -to A[7]
set_location_assignment PIN_46 -to A[6]
set_location_assignment PIN_39 -to A[5]
set_location_assignment PIN_34 -to A[4]
set_location_assignment PIN_32 -to A[3]
set_location_assignment PIN_30 -to A[2]
set_location_assignment PIN_11 -to A[1]
set_location_assignment PIN_7 -to A[0]
set_location_assignment PIN_53 -to D[7]
set_location_assignment PIN_55 -to D[6]
set_location_assignment PIN_59 -to D[5]
set_location_assignment PIN_64 -to D[4]
set_location_assignment PIN_66 -to D[3]
set_location_assignment PIN_68 -to D[2]
set_location_assignment PIN_70 -to D[1]
set_location_assignment PIN_72 -to D[0]
set_location_assignment PIN_77 -to IOW
set_location_assignment PIN_80 -to IOR
set_location_assignment PIN_75 -to MEMW
set_location_assignment PIN_76 -to MEMR
set_location_assignment PIN_129 -to GPIO0
set_location_assignment PIN_126 -to GPIO1
set_location_assignment PIN_100 -to GPIO2
set_location_assignment PIN_85 -to GPIO3
set_location_assignment PIN_104 -to GPIO4
set_location_assignment PIN_128 -to GPIO5
set_location_assignment PIN_132 -to GPIO6
set_location_assignment PIN_127 -to GPIO7
set_location_assignment PIN_125 -to GPIO8
set_location_assignment PIN_120 -to GPIO9
set_location_assignment PIN_115 -to GPIO10
set_location_assignment PIN_58 -to IRQ1
set_location_assignment PIN_67 -to IRQ2
set_location_assignment PIN_33 -to IRQ3
set_location_assignment PIN_38 -to IRQ4
set_location_assignment PIN_52 -to IRQ5
set_location_assignment PIN_54 -to IRQ7
set_location_assignment PIN_60 -to DRQ1
set_location_assignment PIN_65 -to DACK1

set_location_assignment PIN_10 -to OSC
set_location_assignment PIN_28 -to ISACLK
set_location_assignment PIN_42 -to A[10]
set_location_assignment PIN_31 -to A[11]


set_location_assignment PIN_83 -to RESET
set_location_assignment PIN_84 -to SPDIF
set_location_assignment PIN_124 -to GPIO11
set_location_assignment PIN_133 -to GPIO12
set_location_assignment PIN_136 -to GPIO13
set_location_assignment PIN_105 -to GPIO14
set_location_assignment PIN_110 -to GPIO15
set_location_assignment PIN_135 -to CLOCK
set_location_assignment PIN_106 -to FPGA_TX_REQ
set_location_assignment PIN_137 -to FPGA_RX_REQ
set_location_assignment PIN_111 -to STATE0
set_location_assignment PIN_114 -to STATE1
set_location_assignment PIN_119 -to STATE2
set_location_assignment PIN_69 -to AEN
set_location_assignment PIN_71 -to CHRDY
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
